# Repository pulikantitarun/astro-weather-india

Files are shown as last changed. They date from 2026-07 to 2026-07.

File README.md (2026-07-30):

# AstroWeather India — Non-Cellular V5.2

The current non-cellular edition of an affordable, Wi-Fi-connected and almost
entirely 3D-printable weather station for attended astrophotography.




> **Safety:** This is an attended-imaging aid, not a certified weather-safety
> controller. Never use the inexpensive rain plate as the sole input for an
> unattended observatory roof.

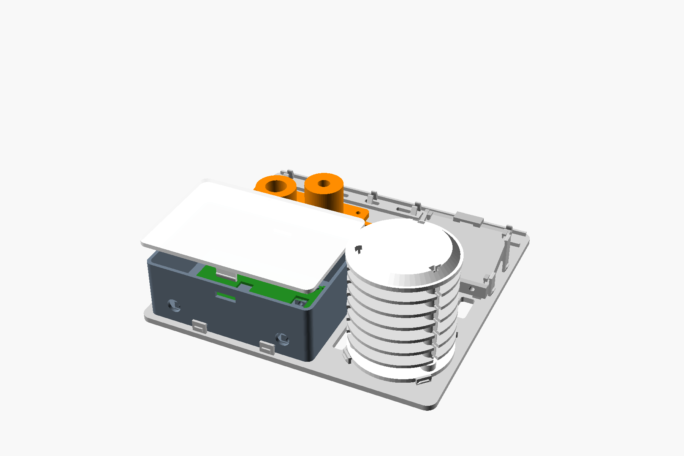
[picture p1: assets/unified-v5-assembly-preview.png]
Non-cellular V5.2 assembly


## Current printable version

The only current printable set is [`stl_unified_v5/`](stl_unified_v5/).

- `K5_Single_Unified_Base_Plate.stl` is one 210 × 200 mm backplane.
- All modules remain individually serviceable.
- The enclosure, lid, carrier, shield, sky head and rain cradle snap together.
- Six integrated jaws manage the rear cable loom.
- Physical surfaces are intentionally unmarked; filenames identify the parts.
- Print `L5_Fit_Kit_12_PIECES_PRINT_FIRST.stl` before the full build.

The original V5 export from commit `88b9ef8` must not be printed. V5.1 corrects
short carrier posts, dock interference, incomplete rain support, a mounting-slot
clash and open cable guides.

V5.2 also replaces H5, I5 and L5. In V5.1, H5's solid lower plate occupied the
same space as I5's PCB rails and snap fingers, so the sky-head halves could not
seat. V5.2 adds a raised protective rim, support pads, split snap pins and
matched 3.90 mm sockets.

Read the complete [V5.2 printing and assembly guide](docs/UNIFIED_V5.md).

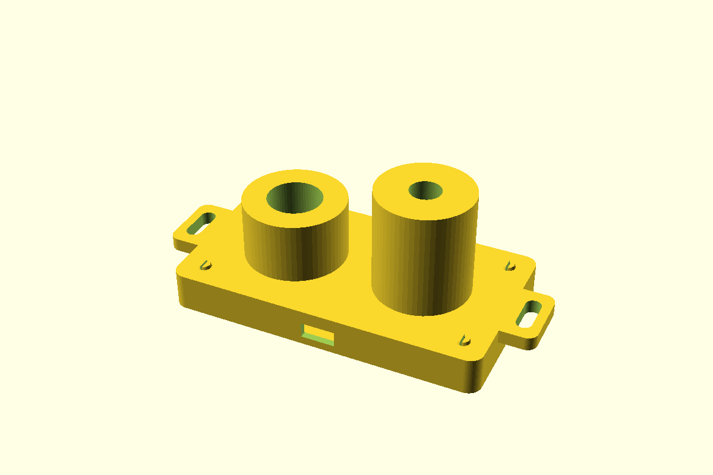
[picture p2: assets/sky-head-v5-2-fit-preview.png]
Corrected V5.2 sky-head fit


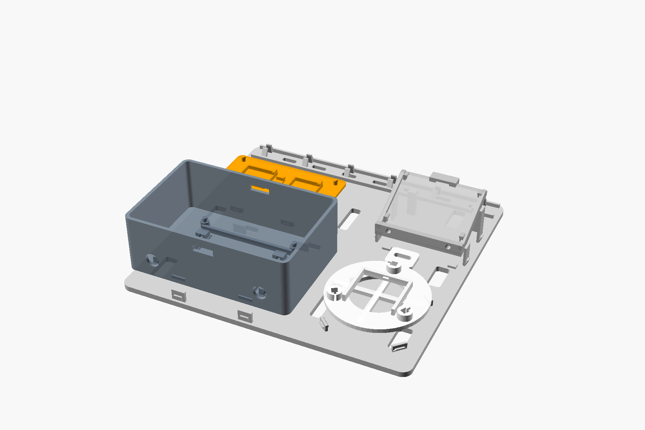
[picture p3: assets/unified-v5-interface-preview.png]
Non-cellular V5.2 interfaces


## Capabilities

- SHT31 temperature and humidity
- calculated dew point and dew margin
- MLX90614 zenith temperature and calibrated thermal-cloud estimate
- TSL2591 relative sky brightness
- reference-calibrated estimated SQM and heuristic Bortle class
- alternating-polarity rain sensing with a ten-minute unsafe latch
- configurable `OK` / `UNSAFE` imaging advisory
- responsive local web dashboard and authenticated settings page
- Wi-Fi setup-access-point fallback
- Telegram reports every 30 or 60 minutes plus rain/safety alerts
- JSON weather API
- ASCOM Alpaca ObservingConditions and SafetyMonitor
- native INDI Weather driver

The clarity score is a calibrated thermal-cloud score. It does not measure
seeing, turbulence, aerosols, transparency or stellar FWHM. SQM must be
calibrated against a reference meter; Bortle remains a heuristic estimate.

## Electronics

All digital sensors share the ESP32 I²C bus:

| ESP32 | Function |
|---|---|
| 3V3 | sensor power |
| GND | common ground |
| GPIO21 | SDA |
| GPIO22 | SCL |
| GPIO32 | rain electrode A network |
| GPIO33 | rain electrode B network |

Use the exposed-trace rain plate without its LM393 comparator board. See
[`docs/WIRING.csv`](docs/WIRING.csv), [`docs/BOM_India.csv`](docs/BOM_India.csv)
and [`docs/ASSEMBLY_GUIDE.md`](docs/ASSEMBLY_GUIDE.md).

## Firmware

```powershell
cd firmware
copy AstroWeather_ESP32\secrets.example.h AstroWeather_ESP32\secrets.h
python -m platformio run
python -m platformio run --target upload
```

If Wi-Fi is not configured, connect to `AstroWeather-Setup` and open
`http://192.168.4.1/settings`. Change the default administrator and setup
passwords immediately.

## Validation

All 15 current meshes pass watertightness, winding, component-count,
positive-volume, Z=0 and K1C/K2 build-envelope checks. Installed-state CGAL
intersections are empty for the carrier, enclosure dock, shield, sky head and
rain cradle. Firmware, configuration, SQM, ASCOM and INDI checks run in GitHub
Actions.

Digital checks do not prove PETG snap force, sensor-board clone dimensions,
weather sealing or field calibration. Approve the supplied fit kit and perform
staged attended testing.

## Source and licence

The editable entry point is
[`cad/AstroWeather_Unified_Base_v5.scad`](cad/AstroWeather_Unified_Base_v5.scad).
The other SCAD files in `cad/` are required source modules for that current
design, not separately supported printable editions.

Licensed under GNU AGPL-3.0-or-later.

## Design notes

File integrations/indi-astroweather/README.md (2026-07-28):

# AstroWeather INDI driver

This driver reads the station's local `/api/weather` JSON endpoint and exposes
standard INDI Weather parameters plus rain and estimated Bortle details.

## Build and install

On a Debian/Ubuntu-based INDI computer:

```bash
sudo apt update
sudo apt install build-essential cmake libindi-dev libcurl4-openssl-dev nlohmann-json3-dev
cmake -S . -B build -DCMAKE_BUILD_TYPE=Release
cmake --build build --parallel
sudo cmake --install build
```

Restart the INDI server, select **AstroWeather India** under Weather, then set
the endpoint to `http://astroweather.local/api/weather`.

The driver is intended for normal INDI installations including KStars/Ekos,
Astroberry and StellarMate. Closed appliances that do not permit third-party
INDI driver installation, including standard ASIAIR firmware, are not
guaranteed to support it.

`WEATHER_SKY_QUALITY` is only updated after `SQM_CAL_OFFSET` is calibrated in
the ESP32 firmware. The binary rain plate is exposed as a dry/wet safety
parameter; it is not misreported as a measured rain rate.

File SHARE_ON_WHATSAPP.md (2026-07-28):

# WhatsApp sharing text

## Short group message

🌦️ **AstroWeather India — DIY weather station for astrophotography**

I have designed and open-sourced an affordable ESP32 weather station for
attended astrophotography. It measures temperature, humidity, dew point,
dew margin, infrared cloud cover, relative sky brightness and rain, and provides
a live Wi-Fi dashboard with an imaging OK/UNSAFE advisory.

✅ Almost completely 3D printable
✅ Support-free parts for Creality K1C and K2 printers
✅ ESP32 web dashboard + JSON API
✅ Locally calibrated cloud and rain thresholds
✅ All STL, OpenSCAD, firmware, wiring and assembly files included
✅ AGPL-3.0 open-source licence

💰 Approximate complete cost: **₹2,900 plus shipping**
Electronics and assembly supplies: ₹2,617.70
PETG and mounting straps: approximately ₹250

GitHub: https://github.com/pulikantitarun/astro-weather-india

Version 1.2 also works as an ASCOM Alpaca ObservingConditions + SafetyMonitor
device directly from the ESP32, and includes a native INDI Weather driver for
KStars/Ekos-compatible systems.

Version 1.3 adds a phone-friendly Settings page for Wi-Fi, Telegram and weather
limits, with optional 30/60-minute reports plus immediate rain and unsafe
alerts. No additional electronics are needed.

⚠️ This is an attended-imaging advisory device, not a certified unattended-roof
safety controller.

## Detailed group message

🔭🌦️ **AstroWeather India — affordable open-source astrophotography weather
station**

I wanted a practical weather monitor that Indian astrophotographers could build
without expensive imported observatory hardware, so I designed this modular
ESP32 station.

It provides:

• air temperature and humidity
• calculated dew point and dew margin
• infrared zenith temperature
• locally calibrated cloud percentage
• thermal clarity score
• relative zenith lux, full-spectrum and IR counts
• reference-calibrated estimated SQM and estimated Bortle class
• corrosion-reduced rain detection with a 10-minute unsafe latch
• live phone/PC dashboard over Wi-Fi
• JSON API for future Home Assistant, Node-RED or observatory integration
• automatic imaging OK/UNSAFE advisory

The printable package has physically labelled A-L parts, a radiation shield,
twin-sensor sky head, sloped rain mount, electronics box, fit-test pieces and
support-free K1C/K2 print orientations.

**Approximate July 2026 India cost**

• ESP32, MLX90614, rain sensor, wiring, solder, flux and power: ₹1,550
• SHT31: ₹312.70
• TSL2591: ₹755
• PETG and straps: about ₹250
• Complete estimate: **₹2,867.70 before shipping**

All STL files, editable OpenSCAD, ESP32 firmware, BOM, wiring, calibration
guide, validation report and assembly visuals are available here:

https://github.com/pulikantitarun/astro-weather-india

Version 1.2 adds direct ASCOM Alpaca discovery, ObservingConditions and
SafetyMonitor support, plus a buildable native INDI Weather driver for
KStars/Ekos, Astroberry and StellarMate-style installations.

Version 1.3 adds persistent web configuration and optional Telegram weather
reports, rain alerts and safe/unsafe state-change notifications.

Licensed under **AGPL-3.0-or-later** so improvements remain open.

Important: this is intended for supervised imaging. It is not a certified
weather instrument and should not be the sole safety sensor for an unattended
observatory roof.

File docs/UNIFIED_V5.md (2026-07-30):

# V5.2 unified tool-less base

V5 keeps the clean, unmarked V4 snap parts and replaces the separate mounting
arrangement with one `K5_Single_Unified_Base_Plate.stl`.

V5 assembled on one base

V5 snap docks

## What the single plate holds

- A5 electronics enclosure on four push-out service tabs;
- C5 radiation shield in a four-finger circular nest;
- I5/H5 sky head in a four-clip rectangular nest;
- J5 rain cradle at its working slope on four integrated support pads;
- the complete loom in a rear channel with six snap-over bridges.

All sensor assemblies remain individually removable. K5 is the only mounting
backplane.

## V5.1 engineering corrections

The original V5 export in commit `88b9ef8` must not be printed. Its four
carrier pegs were part of the A5 mesh and were not floating, but their retaining
heads ended below the top of O5, so the carrier could sit on them without
latching. A broader installed-state audit also found positive-volume dock
interference, incomplete rain-cradle support, a mounting slot cutting a rain
pedestal and open cable guides that could not retain the loom.

V5.1 corrects those issues as follows:

- all four O5 carrier posts now support the carrier at Z=8.0 mm and project
  their retaining heads 1.0 mm above its 2 mm base;
- the four A5 dock arms no longer intersect the enclosure catch ledges;
- shield and rain-clip root gussets grow away from the captured parts;
- the rain cradle seats on connected front pads and two 6 mm-wide rear
  pedestals whose top plane matches the actual J5 convex-hull underside;
- the rear-right mounting slot was moved clear of its rain pedestal;
- the rear loom lane now uses flexible jaws with a 4.6 mm insertion throat.

Final CGAL installed-state intersections are empty for the carrier, A5 dock,
shield dock, sky dock and rain dock. Surface seating is tested separately from
positive-volume collision.

## V5.2 sky-head correction

V5.1 H5 and I5 cannot close correctly: the four-millimetre H5 plate intersects
I5's raised PCB rails and snap fingers. The intended seated position produced
approximately 1,045 mm³ of collision in the CGAL audit.

V5.2 replaces H5, I5 and L5:

- I5 has a 7 mm seating rim that raises H5 above every PCB feature;
- four 7 mm support pads prevent rocking;
- four longer split pins compress during insertion and recover above H5;
- H5 sockets are 3.90 mm with 0.15 mm nominal diametral snap interference;
- a front rim notch routes the sensor loom without pinching it;
- the installed-state CGAL intersection is empty.

Do not combine a V5.1 H5 or I5 with the corrected counterpart. Reprint all
three replacement files so the socket, pin and fit coupon remain matched.

Corrected V5.2 sky-head fit

## Critical mounting orientation

K5 must remain approximately horizontal and level. The sky apertures must point
at the zenith and the rain plate must retain its designed upward slope.

Do not fasten K5 flat against a vertical wall or mast. Use a horizontal shelf,
mast-top tray or 90-degree metal/printed support bracket beneath it. The long
slots are for securing K5 to that horizontal support.

## Print L5 first

`L5_Fit_Kit_12_PIECES_PRINT_FIRST.stl` contains the ten V4 interface tests plus
an exact K5 edge clip and a 3 mm captured-edge coupon.

Use PETG, a 0.4 mm nozzle, 0.20 mm layers, four walls, five bottom layers,
20% gyroid and supports off. Every joint must click with finger pressure,
release without pliers, and survive ten cycles without whitening.

## Printing K5

K5 is 210 x 200 x 31.2 mm. It fits a 220 x 220 x 250 mm K1C bed with 5 mm
clearance on each X side and 10 mm on each Y side.

- Confirm the build plate is actually 220 x 220 mm and correctly centered.
- Use the supplied flat orientation.
- Do not use a wide external brim; it can exceed the K1C printable area.
- Use five walls, six bottom layers and 25% gyroid for the full backplane.
- PETG is preferred; ASA is better outdoors if the printer is configured for it.
- Clean the bed and verify first-layer calibration across the full area.
- The rain pedestals, cable jaws and small snap hooks print support-free.

## Assembly order

1. Approve all twelve L5 coupons.
2. Press O5 and the electronics into A5, then complete and bench-test wiring.
3. Press A5 into the front-left dock until all four base fingers click.
4. Assemble C5, three F5 rods, six D5 louvers, G5 and E5; press the completed
   shield into the circular dock one clip at a time.
5. Install the sky PCBs in I5, route their loom, click H5 onto I5, then press
   the completed sky head into the rear-left rectangular dock.
6. Rotate J5 from its print orientation into its working slope. Rest it on the
   four rear-right support pads and press each side lip beneath the tall clips.
7. Route all low-voltage wiring into the rear loom lane. Press it below each of
   the six bridges and leave drip/service loops before each sensor.
8. Fit N5 grommets and close B5 only after all live sensor tests pass.

## Removing a module

- A5: push its four K5 fingers outward while lifting the enclosure evenly.
- Shield: support C5 beside a clip and release opposite clips in pairs.
- Sky head: flex only the four low tray clips; never pull on the sensor towers.
- Rain cradle: support the sloped tray and release the low pair before the tall
  rear pair.
- Loom: peel one cable section sideways from each bridge; do not pull on a PCB.

## Print quantities

| STL | Quantity |
|---|---:|
| A5, B5, C5, E5, G5, H5, I5, J5, K5, O5 | 1 each |
| D5 louver | 6 |
| F5 rod | 3 |
| M5 cable clip | 6, only where the loom leaves K5 |
| N5 split grommet | 2 |
| L5 calibration kit | 1 first |

## Physical and outdoor limits

Mesh validation cannot prove snap force, clone-PCB compatibility, wind loading,
fatigue, UV life or weather sealing. K5 creates a larger wind-catching assembly
than the separate mounts. Use redundant UV-resistant safety ties after physical
testing if the station is exposed above people or equipment.

Snap fits do not waterproof A5. Keep cable entries downward, use drip loops and
suitable sealing, and place the electronics beneath shelter where possible.
This remains an advisory station, not the sole unattended roof-safety input.

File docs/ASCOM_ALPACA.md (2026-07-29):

# ASCOM Alpaca setup

The current AstroWeather firmware exposes ASCOM Alpaca directly from the ESP32. No Windows
driver executable, bridge computer or additional electronics are required.

## Devices

The station advertises two independent device number `0` entries:

- **AstroWeather Observing Conditions** — air temperature, humidity, dew point,
  cloud cover, sky temperature, sky brightness and calibrated estimated SQM.
- **AstroWeather Safety Monitor** — the station's combined advisory result,
  including the dry/wet rain plate state.

Both use HTTP port 80. Standard UDP Alpaca discovery listens on port 32227.
The unique IDs are derived from the ESP32 MAC address and remain stable for
that board.

## Windows setup

1. Put the ESP32 and Windows imaging computer on the same local network.
2. Flash the current firmware and confirm
   `http://astroweather.local/api/weather` opens.
3. In an Alpaca-aware ASCOM chooser, discover devices and select the
   AstroWeather Observing Conditions and/or Safety Monitor device.
4. If discovery is blocked, add the device manually using
   `astroweather.local`, port `80`, device number `0`.
5. Permit private-network UDP port `32227` and TCP port `80` in the Windows
   firewall if required.

The endpoints can be checked in a browser:

```text
http://astroweather.local/management/apiversions
http://astroweather.local/management/v1/configureddevices
http://astroweather.local/api/v1/observingconditions/0/temperature
http://astroweather.local/api/v1/safetymonitor/0/issafe
```

## Data mapping

| ASCOM property | Station field | Behaviour |
|---|---|---|
| `Temperature` | `air_c` | degrees Celsius |
| `Humidity` | `humidity` | 0–100% |
| `DewPoint` | `dew_c` | degrees Celsius |
| `CloudCover` | `cloud_percent` | 0–100% |
| `SkyTemperature` | `sky_c` | MLX90614 zenith IR temperature |
| `SkyBrightness` | `lux` | TSL2591 lux |
| `SkyQuality` | `sqm_estimate` | only after reference calibration |
| `IsSafe` | `advisory_safe` | combined advisory, including rain |

Pressure, wind, seeing/FWHM and measured rain rate are deliberately reported
as unsupported. The rain plate detects wet/dry state but cannot measure
millimetres per hour.

## Safety and SQM limits

`IsSafe` is an advisory, not a certified roof-control interlock. Use a
fail-safe, independent rain/roof system for unattended operation.

`SkyQuality` returns an ASCOM value-not-set error until `SQM_CAL_OFFSET` is
calibrated. This prevents an uncalibrated light count from appearing as a
real SQM measurement.

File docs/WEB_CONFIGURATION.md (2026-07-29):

# Web configuration portal

The current firmware stores operating settings in the ESP32's non-volatile memory.
Wi-Fi, Telegram and weather limits can therefore be changed from a phone or
computer without editing source code or reflashing.

## First setup

1. Flash the firmware.
2. If it cannot join a configured Wi-Fi network, connect your phone or computer
   to:
   - network: `AstroWeather-Setup`
   - default password: `astroclear`
3. Open `http://192.168.4.1/settings`.
4. Sign in with:
   - username: `admin`
   - default password: `astroadmin`
5. Immediately set a new settings password and setup-access-point password.
6. Enter the normal Wi-Fi SSID and password.
7. Configure the required weather and Telegram options.
8. Select **Save and restart**.

After a successful connection, use:

```text
http://astroweather.local/
http://astroweather.local/settings
```

If the hostname was changed, replace `astroweather` with the new hostname.

## Configurable values

### Network

- local hostname;
- Wi-Fi SSID and password;
- fallback setup-access-point password;
- settings-page password.

### Telegram

- enable/disable;
- bot token and chat/group ID;
- reports off, every 30 minutes or every hour;
- startup, unsafe, recovery and rain alerts;
- local UTC offset, defaulting to India Standard Time (`330` minutes).

### Weather and calibration

- humidity unsafe limit;
- minimum dew margin;
- cloud unsafe percentage;
- rain raw threshold;
- rain unsafe latch from 1 to 120 minutes;
- clear and overcast thermal calibration deltas;
- SQM calibration offset.

Passwords and the Telegram token are write-only: the page never displays their
stored values. A blank secret field keeps the current value. The Telegram form
also has an explicit option to delete the saved token.

## Persistence and security

Settings survive normal restarts and firmware updates because they are stored
in ESP32 NVS. Erasing the ESP32 flash also erases them.

The configuration page uses HTTP Basic authentication, but local HTTP is not
encrypted. Keep AstroWeather on a trusted private network, change both default
passwords and never expose port 80 through router port forwarding. Wi-Fi
passwords and Telegram tokens must be available to the firmware and are not
encrypted in ordinary ESP32 NVS; physical access to the device should therefore
be treated as access to those credentials.

The public dashboard, JSON API, ASCOM Alpaca and INDI service remain available
without settings credentials so astronomy clients continue to work.

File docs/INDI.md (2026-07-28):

# INDI / KStars / Ekos setup

The source for the native driver is in
`integrations/indi-astroweather`. It polls the ESP32 JSON endpoint and exposes
INDI Weather values to KStars/Ekos and other standard INDI clients.

## Install

Run these commands on the Linux computer that hosts INDI:

```bash
sudo apt update
sudo apt install build-essential cmake libindi-dev libcurl4-openssl-dev nlohmann-json3-dev
cd integrations/indi-astroweather
cmake -S . -B build -DCMAKE_BUILD_TYPE=Release
cmake --build build --parallel
sudo cmake --install build
```

Restart the INDI service. Add **AstroWeather India** as a Weather device, open
its Options tab and set:

```text
http://astroweather.local/api/weather
```

If mDNS is not available, reserve an IP address for the ESP32 in the router
and use `http://192.168.x.x/api/weather`.

## Values

The driver supplies:

- temperature, humidity and dew point;
- cloud cover and sky temperature;
- calibrated estimated sky quality in mag/arcsec²;
- estimated Bortle class;
- dry/wet rain state;
- `WEATHER_FORECAST = 0` for advisory safe or `3` for unsafe.

The rain state and forecast are critical safety parameters. SQM/Bortle are
only updated when calibrated finite values are present in the ESP32 response.

This works with INDI installations that permit third-party driver binaries,
including typical KStars/Ekos, Astroberry and StellarMate systems. Standard
ASIAIR firmware does not provide a supported route for installing arbitrary
third-party INDI drivers, so ASIAIR compatibility is not claimed.

As with the dashboard and Alpaca interface, the INDI status is advisory only
and must not be the sole unattended roof-closing input.

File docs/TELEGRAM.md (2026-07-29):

# Telegram weather reports

The current AstroWeather firmware can send outbound Telegram reports directly from the ESP32.
No additional computer, cloud subscription or electronic component is needed.

## Create the bot

1. Open the official `@BotFather` account in Telegram.
2. Send `/newbot` and follow its instructions.
3. Copy the generated bot token.
4. Open the new bot and send `/start`. A bot cannot initiate a private
   conversation until the user has contacted it.
5. For a group, add the bot to the group and send a message that it can receive.
6. Obtain the private chat or group `chat_id` from the bot's updates.

Treat the token like a password: anyone with it can control the bot. If it is
ever exposed, revoke it through BotFather.

## Configure AstroWeather

1. Open `http://astroweather.local/settings`.
2. Enable Telegram.
3. Paste the bot token and destination chat/group ID.
4. Choose reports every 30 minutes, every hour, or off.
5. Enable the desired event messages:
   - station online;
   - weather changed to unsafe;
   - conditions recovered to safe;
   - rain detected.
6. Keep the UTC offset at `330` for India Standard Time.
7. Save, allow the station to restart, reopen Settings and select
   **Send Telegram test**.

Example:

```text
REGULAR WEATHER REPORT
AstroWeather India - 2026-07-28 21:30

Temperature: 23.4 C
Humidity: 78.0 %
Dew point: 19.4 C
Dew margin: 4.0 C
Cloud cover: 16 %
Clarity: 84 / 100
SQM estimate: 20.65
Estimated Bortle: 4
Rain: dry
Status: ADVISORY SAFE
```

SQM and Bortle are labelled unavailable until a valid SQM calibration exists.
Rain triggers immediately and the safe recovery message is delayed until the
configured rain latch and all other unsafe conditions have cleared.

## Reliability and privacy

- Telegram uses certificate-validated HTTPS and NTP-corrected time.
- The token is never returned by the dashboard or JSON API.
- No inbound router port or Telegram command polling is required.
- If internet access fails, the dashboard, API, ASCOM and INDI remain local and
  operational.
- Event messages that occur entirely during an outage cannot be recovered
  because this inexpensive design does not include persistent message queuing.
- Telegram is an advisory notification channel, not a roof safety interlock.

Official references:

- [Telegram Bot API](https://core.telegram.org/bots/api)
- [Telegram BotFather and bot features](https://core.telegram.org/bots/features)

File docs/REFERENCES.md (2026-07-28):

# Technical references

- [Adafruit TSL2591 gain, integration time, raw channels and lux calculation](https://learn.adafruit.com/adafruit-tsl2591/wiring-and-test)
- [Unihedron SQM-LR operator manual and mag/arcsec² response format](https://unihedron.com/projects/darksky/cd/SQM-LR/SQM-LR_Users_manual.pdf)
- [Introducing the Bortle Dark-Sky Scale, John E. Bortle](https://www.skyandtelescope.org/wp-content/uploads/BortleDarkSkyScale.pdf)
- [ASCOM Master ObservingConditions interface](https://ascom-standards.org/newdocs/observingconditions.html)
- [ASCOM Alpaca API reference](https://ascom-standards.org/AlpacaDeveloper/ASCOMAlpacaAPIReference.html)
- [INDI WeatherInterface documentation](https://docs.indilib.org/interfaces/weather-interface.html)
- [Telegram Bot API](https://core.telegram.org/bots/api)
- [Telegram BotFather and bot features](https://core.telegram.org/bots/features)

The TSL2591 does not natively report SQM. AstroWeather applies the astronomical
magnitude relationship to fixed-gain visible counts after calibration against a
reference SQM. The reported Bortle value is a heuristic label and is not a
replacement for the visual assessment described by Bortle.

The network integrations intentionally use the published ASCOM Alpaca and INDI
Weather interfaces. Unsupported physical measurements such as pressure, wind,
seeing and rain rate are not inferred.

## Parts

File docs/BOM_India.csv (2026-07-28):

Item | Qty | Approximate INR | Required
ESP32 38-pin DevKit | 1 | 381 | Yes
SHT31 temperature/humidity breakout | 1 | 312.70 | Yes
MLX90614 GY-906 IR thermometer module | 1 | 670 | Yes
TSL2591 19x16 mm light sensor | 1 | 755 | Yes
Exposed-trace rain sensor module | 1 | 49 | Yes
Mixed M-M M-F F-F jumper set | 1 | 139 | Yes
100k resistor pack | 1 | 13 | Yes
1M resistor pack | 1 | 13 | Yes
2x3 inch vero board | 1 | 13 | Yes
4 mm heat-shrink tube 1 m | 1 | 13 | Yes
Electronics flux 10 g | 1 | 25 | Yes
Solder wire 10 g | 1 | 39 | Yes
5 V 2 A adapter with Micro-USB cable | 1 | 195 | Yes
PETG filament approximately 250 g | 1 | 200 | Yes
Reusable mounting straps | 2 | 50 | Yes
Conformal coating for boards only | 1 | 250 | Optional
ELECTRONICS AND ASSEMBLY SUPPLIES SUBTOTAL |  | 2617.70 | Before shipping
ESTIMATED COMPLETE BUILD |  | 2867.70 | Before shipping excluding optional coating

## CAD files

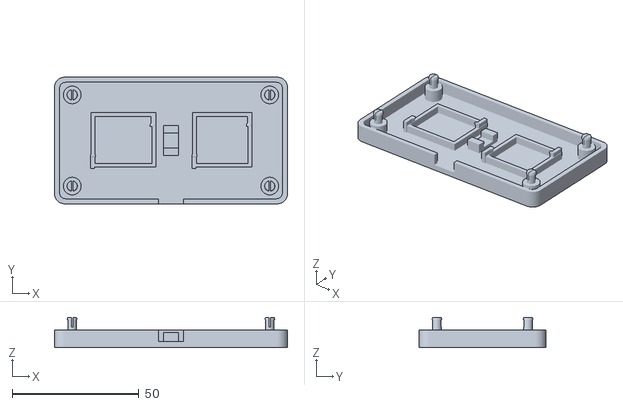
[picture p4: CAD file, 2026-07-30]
stl_unified_v5/I5_PCB_Snap_Sky_Tray.stl
92.0 x 50.0 x 11.9

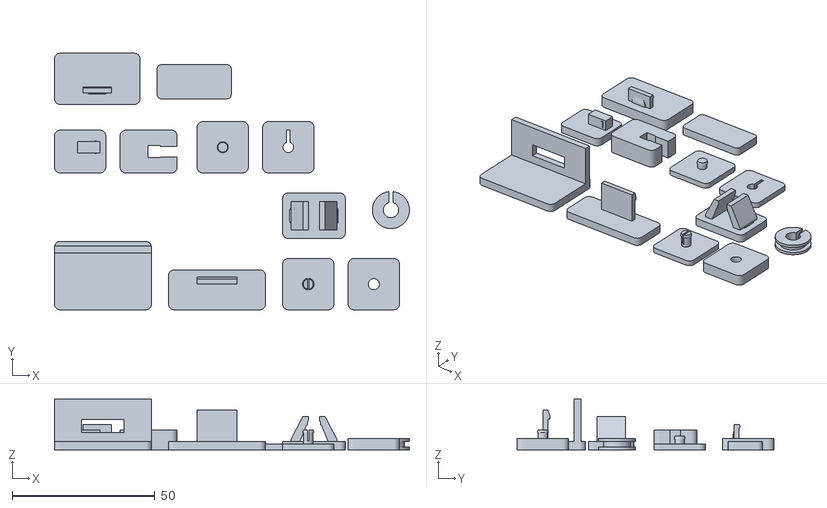
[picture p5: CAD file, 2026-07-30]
stl_unified_v5/L5_Fit_Kit_12_PIECES_PRINT_FIRST.stl
124.5 x 90.0 x 17.8

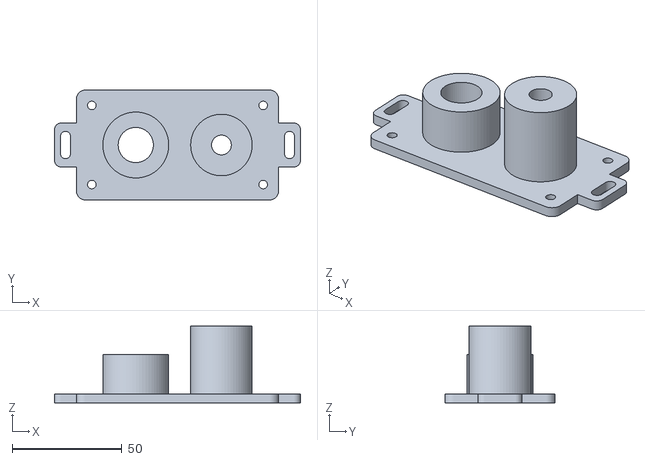
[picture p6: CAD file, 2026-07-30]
stl_unified_v5/H5_Sky_Head_Top.stl
112.0 x 50.0 x 35.0

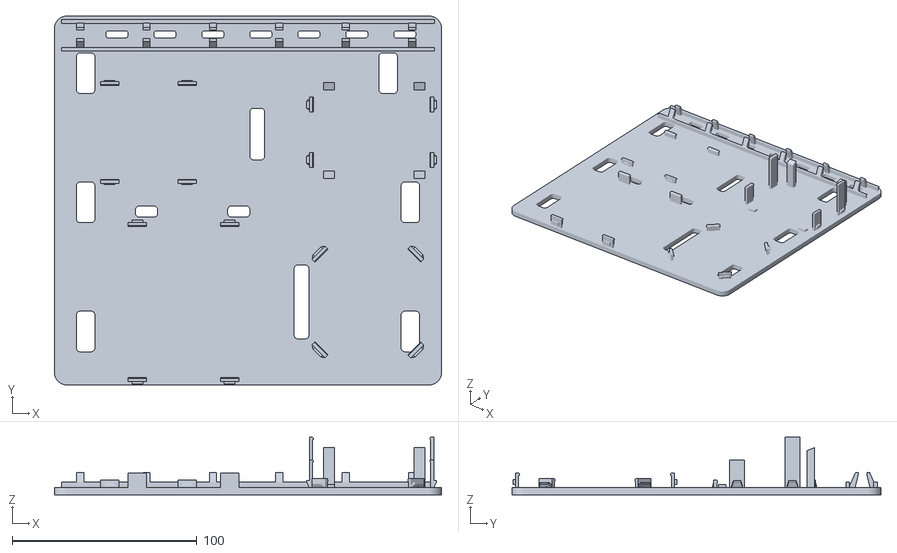
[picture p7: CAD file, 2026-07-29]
stl_unified_v5/K5_Single_Unified_Base_Plate.stl
210.0 x 200.0 x 31.2

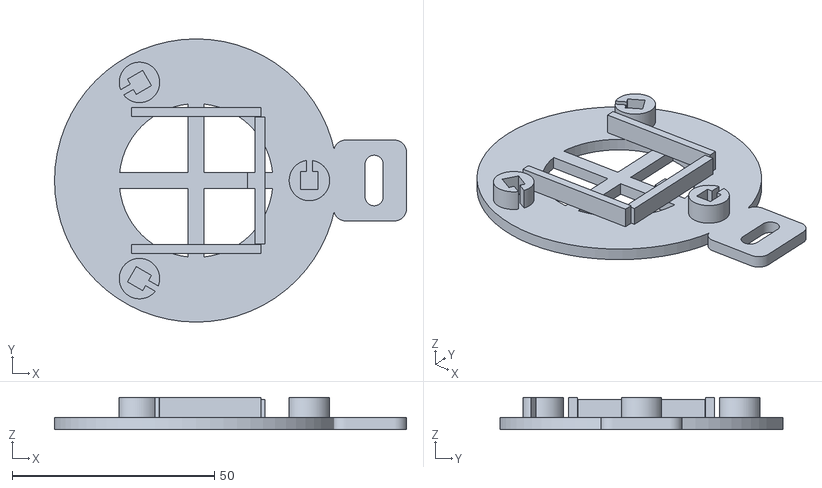
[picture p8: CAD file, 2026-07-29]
stl_unified_v5/C5_Click_Shield_Base.stl
87.0 x 70.0 x 8.00

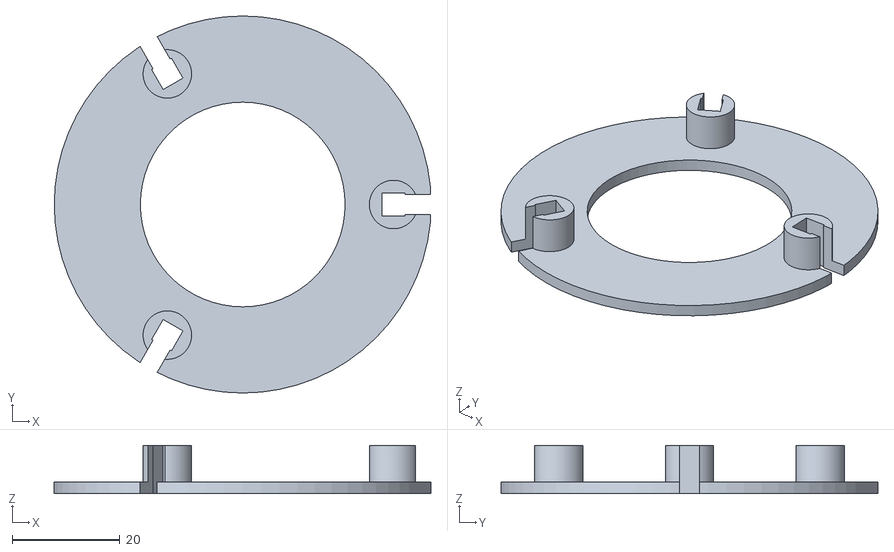
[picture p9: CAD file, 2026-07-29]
stl_unified_v5/D5_Side_Snap_Louver_PRINT_6.stl
69.9 x 70.0 x 9.00

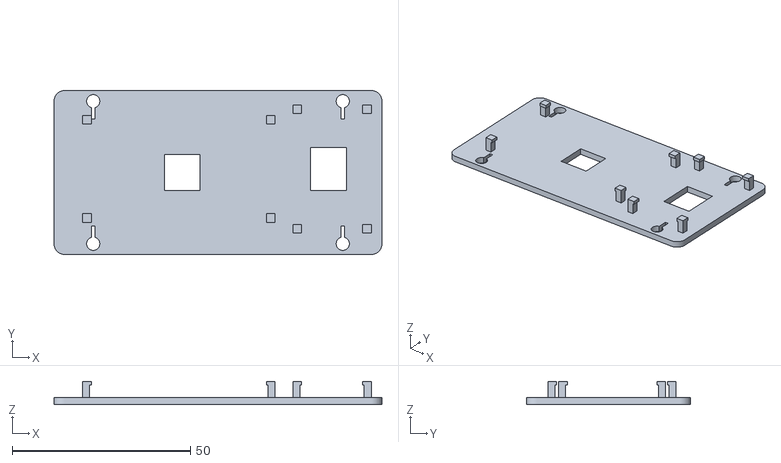
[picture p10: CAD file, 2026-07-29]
stl_unified_v5/O5_Snap_Electronics_Carrier.stl
92.0 x 46.0 x 6.50

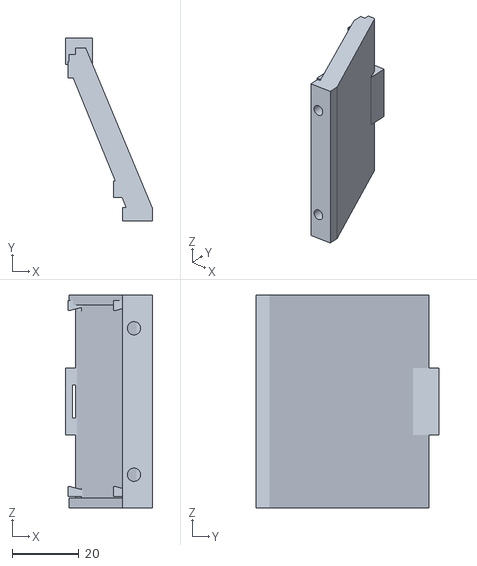
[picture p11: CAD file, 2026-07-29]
stl_unified_v5/J5_Compliant_Rain_Cradle.stl
26.0 x 55.0 x 64.0

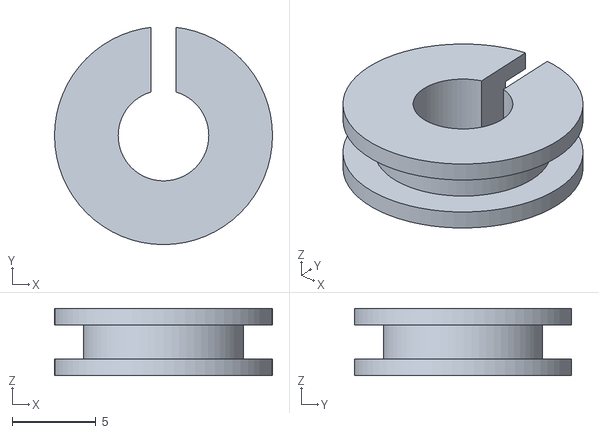
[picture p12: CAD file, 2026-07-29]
stl_unified_v5/N5_Split_Grommet_PRINT_2.stl
13.0 x 13.0 x 4.00

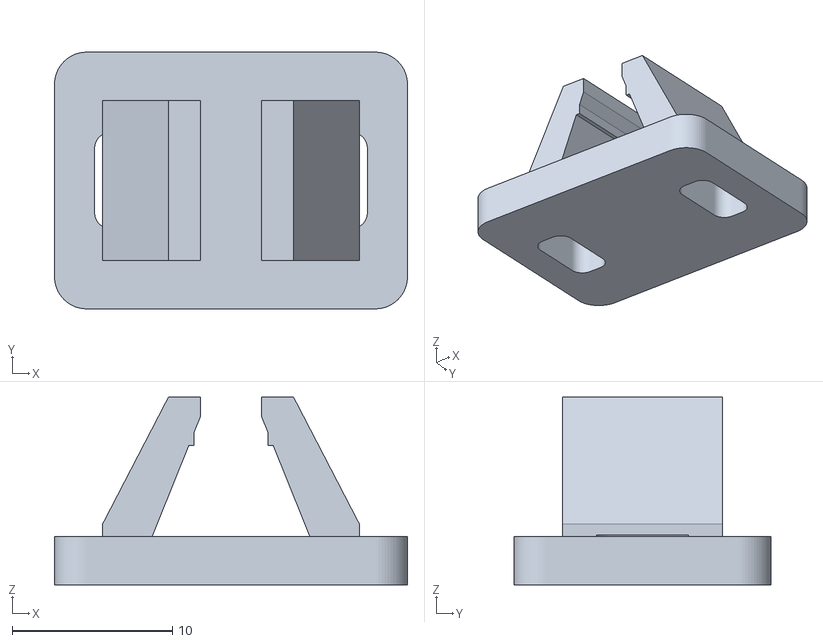
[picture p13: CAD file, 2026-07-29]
stl_unified_v5/M5_Cable_Clip_PRINT_6.stl
22.0 x 16.0 x 11.7

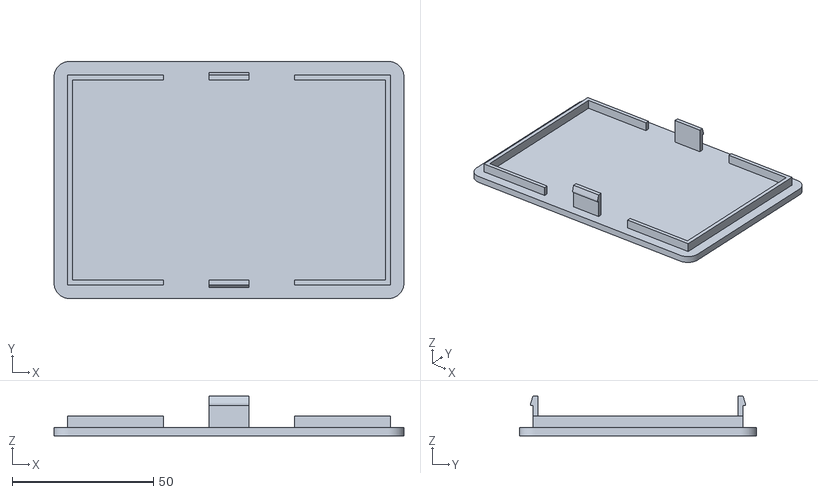
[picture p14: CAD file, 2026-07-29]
stl_unified_v5/B5_Release_Lid.stl
124.0 x 84.0 x 14.0

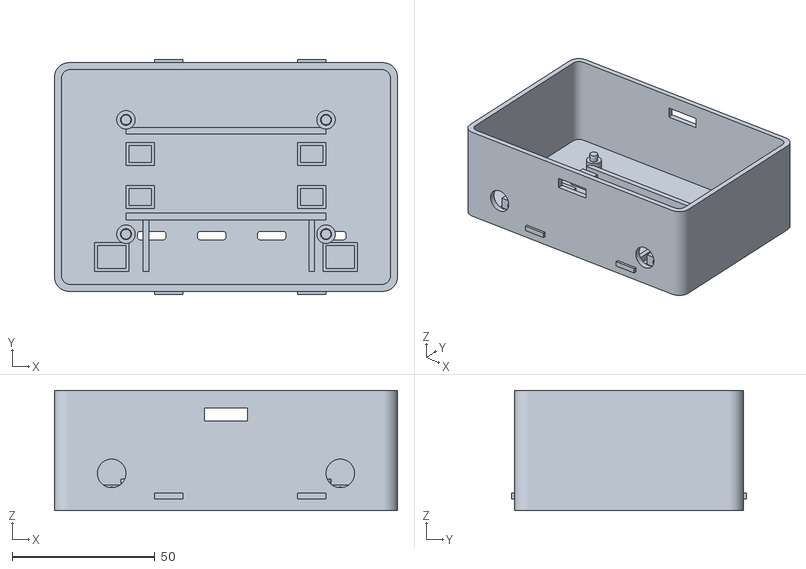
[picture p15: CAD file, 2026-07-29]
stl_unified_v5/A5_Clean_Electronics_Box.stl
120.0 x 82.2 x 42.0

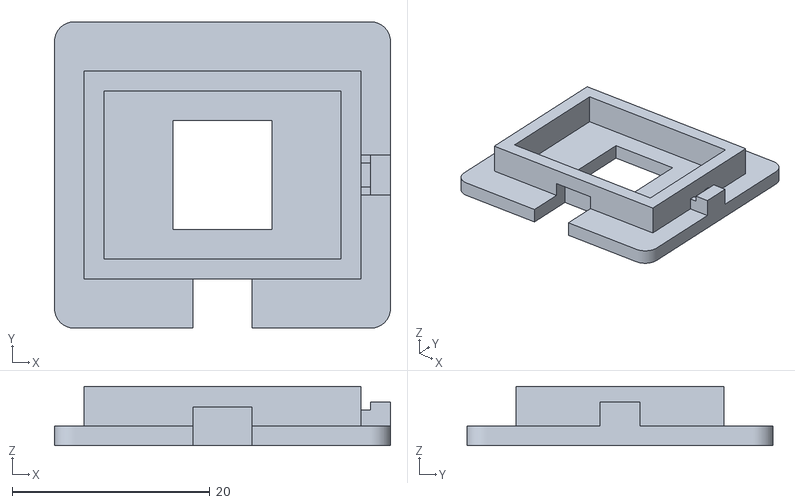
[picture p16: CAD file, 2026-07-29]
stl_unified_v5/G5_Click_SHT31_Sled.stl
34.0 x 31.0 x 6.00

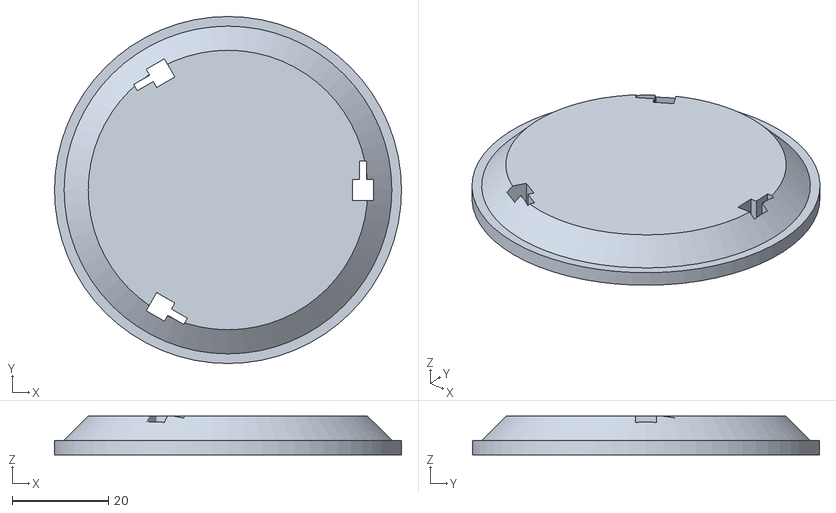
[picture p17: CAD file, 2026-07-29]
stl_unified_v5/E5_Click_Shield_Roof.stl
72.0 x 72.0 x 8.00

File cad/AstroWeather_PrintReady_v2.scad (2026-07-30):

/*
  SPDX-License-Identifier: AGPL-3.0-or-later
  Copyright (C) 2026 Tarun and contributors

 AstroWeather India - K1C/K2 print-ready mechanical revision 2

 Every exported STL is placed in its intended print orientation.
 No supports are intended with a 0.4 mm nozzle and 0.20 mm layers.

  1 A_Electronics_Box
  2 B_Box_Lid
  3 C_Shield_Base
  4 D_Shield_Louver (print 6)
  5 E_Shield_Roof
  6 F_Shield_Rod (print 3)
  7 G_SHT31_Sled
  8 H_Sky_Head_Top
  9 I_Sky_Head_Tray
 10 J_Rain_Plate_Mount
 11 K_Mounting_Plate
 12 L_Fit_Kit_4_PIECES (print first)
 90 exploded assembly preview
*/

$fn = 64;
part_id = 90;
fit = 0.35;
wall = 2.4;
lid_clearance_per_side = 0.30;
peg_d = 3.60;
// H5 socket is deliberately larger than the legacy friction socket. The
// current split snap pin provides retention without relying on an undersized
// printed hole.
peg_clearance_d = 0.30;
board_clearance = 0.50;

module rr2d(s=[20,20],r=3) {
    hull()
        for (x=[r,s[0]-r], y=[r,s[1]-r])
            translate([x,y]) circle(r=r);
}

module rrbox(s=[20,20,5],r=3) {
    linear_extrude(s[2]) rr2d([s[0],s[1]],r);
}

module mark(txt, p=[0,0,0], size=5, h=0.55) {
    if (is_undef($show_part_labels) || $show_part_labels)
        translate(p) linear_extrude(h)
            text(txt,size=size,font="Liberation Sans:style=Bold",
                 halign="center",valign="center");
}

module A_box() {
    difference() {
        rrbox([120,80,42],5);
        translate([wall,wall,3])
            rrbox([120-2*wall,80-2*wall,42],3.2);
        // Down-facing cable entries when installed vertically.
        translate([20,-1,13]) rotate([-90,0,0]) cylinder(d=8,h=wall+2);
        translate([100,-1,13]) rotate([-90,0,0]) cylinder(d=8,h=wall+2);
        for (x=[25:22:91])
            translate([x,15,-0.1]) cube([12,3,4]);
    }
    // Generic ESP32/perfboard rails.
    for (y=[22,56]) translate([25,y,3]) cube([70,2.2,4]);
    // Cable anchors.
    for (x=[16,104])
        translate([x,12,3]) difference() {
            cube([8,8,6],center=true);
            rotate([90,0,0]) cylinder(d=3.5,h=10,center=true);
        }
    mark("A  BOX",[60,40,3],6);
}

module B_lid() {
    union() {
        rrbox([124,84,3],5.5);
        // Friction plug. Sand lightly if the fit coupon is tight.
        translate([(124-(115.2-2*lid_clearance_per_side))/2,
                   (84-(75.2-2*lid_clearance_per_side))/2,3])
            difference() {
                rrbox([115.2-2*lid_clearance_per_side,
                       75.2-2*lid_clearance_per_side,4],3);
                translate([2.4,2.4,-0.1])
                    rrbox([110.4-2*lid_clearance_per_side,
                           70.4-2*lid_clearance_per_side,4.2],2);
            }
        mark("B  LID",[62,42,3],6);
    }
}

module C_shield_base() {
    difference() {
      union() {
        difference() {
            cylinder(d=70,h=3);
            translate([0,0,-0.1]) cylinder(d=38,h=3.2);
        }
        // Crossbars and sled guides.
        translate([-31,-2,0]) cube([62,4,3]);
        translate([-2,-31,0]) cube([4,62,3]);
        translate([-16,-18,3]) cube([32,2.2,5]);
        translate([-16,15.8,3]) cube([32,2.2,5]);
        // Square rod sockets.
        for (a=[0,120,240])
            rotate([0,0,a]) translate([28,0,0])
                difference() {
                    cylinder(d=10,h=8);
                    translate([-2.25,-2.25,2]) cube([4.5,4.5,6.2]);
                }
        translate([34,-10,0]) rrbox([18,20,3],3);
        mark("C",[0,-27,3],5);
      }
      translate([44,0,-0.1]) hull() {
          translate([0,-4,0]) cylinder(d=4.5,h=3.2);
          translate([0,4,0]) cylinder(d=4.5,h=3.2);
      }
    }
}

module D_louver() {
    difference() {
        union() {
            difference() {
                cylinder(d=70,h=2.2);
                translate([0,0,-0.1]) cylinder(d=38,h=2.4);
            }
            // Integrated spacers face upward; each new louver rests on them.
            for (a=[0,120,240])
                rotate([0,0,a]) translate([28,0,0])
                    cylinder(d=9,h=9);
            mark("D",[0,-27,2.2],4);
        }
        for (a=[0,120,240])
            rotate([0,0,a]) translate([28,0,-0.1])
                translate([-2.35,-2.35,0]) cube([4.7,4.7,9.2]);
    }
}

module E_roof() {
    difference() {
        union() {
            cylinder(d=72,h=3);
            translate([0,0,3]) cylinder(d1=68,d2=58,h=5);
            mark("E",[0,-25,8],4);
        }
        for (a=[0,120,240])
            rotate([0,0,a]) translate([28,0,-0.1])
                translate([-2.3,-2.3,0]) cube([4.6,4.6,8.3]);
    }
}

module F_rod() {
    // Printed flat. Three identical rods slide through the D louvers.
    union() {
        translate([2,0,0]) cube([64,4,4]);
        translate([0,0,0]) hull() {
            translate([0.8,0.4,0.4]) cube([1.2,3.2,3.2]);
            translate([2,0,0]) cube([1,4,4]);
        }
        translate([66,0,0]) hull() {
            cube([1,4,4]);
            translate([1,0.4,0.4]) cube([1.2,3.2,3.2]);
        }
        mark("F",[34,2,4],3.2,0.45);
    }
}

module G_sht_sled() {
    difference() {
        union() {
            rrbox([34,31,2],2);
            for (x=[3,29]) translate([x,5,2]) cube([2,21,4]);
            for (y=[5,24]) translate([3,y,2]) cube([28,2,4]);
            mark("G",[17,27.5,2],4);
        }
        translate([12,10,-0.1]) cube([10,11,2.2]);
        translate([14,-0.1,-0.1]) cube([6,7,4]);
    }
}

module H_sky_top() {
    difference() {
        union() {
            rrbox([92,50,4],4);
            translate([-10,15,0]) rrbox([112,20,4],3);
            translate([27,25,4]) difference() {
                cylinder(d=30,h=18);
                translate([0,0,-0.1]) cylinder(d=16,h=18.2);
            }
            translate([66,25,4]) difference() {
                cylinder(d=28,h=31);
                translate([0,0,-0.1]) cylinder(d1=12,d2=9,h=31.2);
            }
            mark("H  SKY TOP",[46,7,4],4.5);
        }
        // Sensor apertures.
        translate([27,25,-0.1]) cylinder(d=16,h=4.2);
        translate([66,25,-0.1]) cylinder(d=10,h=4.2);
        // Friction peg sockets.
        for (x=[7,85], y=[7,43])
            translate([x,y,-0.1])
                cylinder(d=peg_d+peg_clearance_d,h=4.2);
        for (x=[-5,97])
            translate([x,25,-0.1]) hull() {
                translate([0,-4,0]) cylinder(d=4.5,h=4.2);
                translate([0,4,0]) cylinder(d=4.5,h=4.2);
            }
    }
}

module pocket_rails(c=[27,25], s=[22,18]) {
    translate([c[0]-s[0]/2-1.5,c[1]-s[1]/2-1.5,2]) {
        cube([s[0]+3+board_clearance,1.5,3]);
        translate([0,s[1]+1.5+board_clearance,0])
            cube([s[0]+3+board_clearance,1.5,3]);
        cube([1.5,s[1]+3+board_clearance,3]);
        translate([s[0]+1.5+board_clearance,0,0])
            cube([1.5,s[1]+3+board_clearance,3]);
    }
}

module I_sky_tray() {
    union() {
        rrbox([92,50,2],4);
        pocket_rails([27,25],[22,18]);
        pocket_rails([66,25],[20,18]);
        for (x=[7,85], y=[7,43])
            translate([x,y,2]) cylinder(d1=peg_d,d2=peg_d-0.1,h=4);
        mark("I  SENSOR TRAY",[46,7,2],4);
    }
}

module J_rain_raw() {
    difference() {
      union() {
        // Sloped 3 mm tray.
        hull() {
            translate([0,0,0]) cube([64,4,3]);
            translate([0,48,20]) cube([64,4,3]);
        }
        // Side lips.
        for (x=[0,61])
            hull() {
                translate([x,2,2]) cube([3,4,5]);
                translate([x,46,20]) cube([3,4,5]);
            }
        translate([0,0,2]) cube([64,4,7]);
        translate([22,47,18]) difference() {
            cube([20,8,8]);
            translate([5,-0.1,2]) cube([10,8.2,4]);
        }
        if (is_undef($show_part_labels) || $show_part_labels)
            // Side label; this becomes upward-facing after export rotation.
            translate([0,25,11]) rotate([90,0,90])
                linear_extrude(0.6)
                    text("J RAIN",size=5,font="Liberation Sans:style=Bold",
                         halign="center",valign="center");
      }
      for (x=[10,54])
          translate([x,-0.1,5.5]) rotate([-90,0,0])
              cylinder(d=4,h=4.2);
    }
}

module J_rain_mount() {
    // Rotate onto the broad left cheek: stable, support-free print orientation.
    translate([26,0,0]) rotate([0,-90,0]) J_rain_raw();
}
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

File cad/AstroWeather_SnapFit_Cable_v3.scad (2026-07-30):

/*
  SPDX-License-Identifier: AGPL-3.0-or-later
  Copyright (C) 2026 Tarun and contributors

  AstroWeather India - non-cellular snap-fit and cable-management revision 3

  Every exported STL is in its intended support-free print orientation.
  Print part 12 first and tune the parameters below before the full set.

   1 A3_SnapFit_Electronics_Box
   2 B3_Release_Lid
   3 C_Shield_Base (unchanged sensor geometry)
   4 D_Shield_Louver (print 6)
   5 E_Shield_Roof
   6 F_Shield_Rod (print 3)
   7 G_SHT31_Sled
   8 H_Sky_Head_Top
   9 I3_SnapFit_Sky_Tray
  10 J_Rain_Plate_Mount
  11 K3_Cable_Managed_Mounting_Plate
  12 L3_Fit_Kit_6_PIECES_PRINT_FIRST
  13 M3_Cable_Clip (print 6)
  14 N3_Split_Grommet (print 2)
  90 exploded assembly preview
*/

use <AstroWeather_PrintReady_v2.scad>

$fn = 64;
part_id = 90;

wall = 2.4;
lid_clearance_per_side = 0.35;
snap_tab_width = 14;
snap_tab_thickness = 1.8;
snap_tab_height = 11.2;
snap_hook = 0.75;
snap_window_clearance = 0.45;

sky_peg_shaft_d = 3.45;
sky_peg_head_d = 4.05;
sky_peg_shaft_h = 4.25;
sky_peg_head_h = 0.90;
sky_socket_d = 3.90; // Matches the enlarged H socket.
sky_top_seat_z = 7.0;
sky_peg_base_z = 6.80;
board_clearance = 0.50;

cable_entry_d = 10.0;
grommet_body_d = 9.55;
grommet_flange_d = 13.0;
grommet_cable_d = 5.4;
cable_clip_d = 5.5;

module v3_mark(txt, p=[0,0,0], size=5, h=0.55) {
    if (is_undef($show_part_labels) || $show_part_labels)
        translate(p) linear_extrude(h)
            text(txt,size=size,font="Liberation Sans:style=Bold",
                 halign="center",valign="center");
}

module snap_window(y_back=false) {
    translate([60-snap_tab_width/2-snap_window_clearance,
               y_back ? 77.3 : -0.1,
               31.3])
        cube([snap_tab_width+2*snap_window_clearance,
              2.8,
              4.6]);
}

module cable_anchor(x, y=12) {
    translate([x,y,3])
        difference() {
            union() {
                translate([-5,-4,0]) cube([10,8,6]);
                translate([-6,-5,0]) cube([12,10,1.2]);
            }
            translate([0,0,3.4])
                rotate([90,0,0]) cylinder(d=3.6,h=12,center=true);
        }
}

module board_tie_anchor(x,y) {
    translate([x,y,3])
        difference() {
            union() {
                translate([-4,-3,0]) cube([8,6,5]);
                translate([-5,-4,0]) cube([10,8,1]);
            }
            translate([0,0,3])
                rotate([90,0,0]) cylinder(d=3.4,h=9,center=true);
        }
}

module A3_box() {
    difference() {
        union() {
            difference() {
                rrbox([120,80,42],5);
                translate([wall,wall,3])
                    rrbox([120-2*wall,80-2*wall,42],3.2);
                // Two labelled down-facing entries: power and combined sensor loom.
                translate([20,-1,13])
                    rotate([-90,0,0]) cylinder(d=cable_entry_d,h=wall+2);
                translate([100,-1,13])
                    rotate([-90,0,0]) cylinder(d=cable_entry_d,h=wall+2);
                // Vent/drain slots stay on the installed underside.
                for (x=[29:21:92])
                    translate([x,18,-0.1]) rrbox([10,3,4],1);
            }
            // Generic ESP32/perfboard rails.
            for (y=[25,55]) translate([25,y,3]) cube([70,2.4,4]);
            // Low cable-routing fences guide wires away from the lid latches.
            for (x=[31,89]) translate([x,7,3]) cube([2,18,3]);
            cable_anchor(20);
            cable_anchor(100);
            for (x=[30,90], y=[33,48]) board_tie_anchor(x,y);
            v3_mark("A3  SNAP BOX",[60,68,3],5);
            v3_mark("POWER",[20,22,3],3.2);
            v3_mark("SENSORS",[100,22,3],3.2);
            if (is_undef($show_part_labels) || $show_part_labels) {
                translate([60,0,38.5]) rotate([-90,0,0])
                    linear_extrude(0.5)
                        text("PUSH",size=3.2,
                             font="Liberation Sans:style=Bold",
                             halign="center",valign="center");
                translate([60,80,38.5]) rotate([90,0,0])
                    linear_extrude(0.5)
                        text("PUSH",size=3.2,
                             font="Liberation Sans:style=Bold",
                             halign="center",valign="center");
            }
        }
        snap_window(false);
        snap_window(true);
    }
}

module snap_tongue(front=true) {
    union() {
        translate([-snap_tab_width/2,0,0])
            cube([snap_tab_width,snap_tab_thickness,snap_tab_height]);
        if (front)
            hull() {
                translate([-snap_tab_width/2,
                           -snap_hook,
                           snap_tab_height-3.2])
                    cube([snap_tab_width,snap_tab_thickness+snap_hook,0.8]);
                translate([-snap_tab_width/2,
                           0,
                           snap_tab_height-0.25])
                    cube([snap_tab_width,snap_tab_thickness,0.25]);
            }
        else
            hull() {
                translate([-snap_tab_width/2,
                           0,
                           snap_tab_height-3.2])
                    cube([snap_tab_width,snap_tab_thickness+snap_hook,0.8]);
                translate([-snap_tab_width/2,
                           0,
                           snap_tab_height-0.25])
                    cube([snap_tab_width,snap_tab_thickness,0.25]);
            }
        // Root gusset remains below the flexing section.
        hull() {
            translate([-snap_tab_width/2,0,0])
                cube([snap_tab_width,snap_tab_thickness,0.5]);
            translate([-snap_tab_width/2+2,0,2.2])
                cube([snap_tab_width-4,snap_tab_thickness,0.5]);
        }
    }
}

module B3_lid() {
    plug_x = 115.2-2*lid_clearance_per_side;
    plug_y = 75.2-2*lid_clearance_per_side;
    ox = (124-plug_x)/2;
    oy = (84-plug_y)/2;
    ring_t = 1.8;

    union() {
        rrbox([124,84,3],5.5);

        // Alignment rails. Central gaps leave each latch tongue free to flex.
        translate([ox,oy,2.8]) {
            cube([ring_t,plug_y,4.2]);
            translate([plug_x-ring_t,0,0]) cube([ring_t,plug_y,4.2]);
            for (x=[0,plug_x-34]) {
                translate([x,0,0]) cube([34,ring_t,4.2]);
                translate([x,plug_y-ring_t,0])
                    cube([34,ring_t,4.2]);
            }
        }

        // Releasable opposing latches: press both A3 windows while lifting B3.
        translate([62,oy,2.8]) snap_tongue(true);
        translate([62,oy+plug_y-snap_tab_thickness,2.8])
            snap_tongue(false);

        v3_mark("B3  RELEASE LID",[62,42,3],5.5);
        v3_mark("PRESS SIDES",[62,18,3],3.2);
    }
}

module sky_snap_peg() {
    // The split lets the two halves compress through H5, then recover above
    // its four-millimetre plate. The unsplit lower section remains robust.
    difference() {
        union() {
            cylinder(d=sky_peg_shaft_d,h=sky_peg_shaft_h);
            translate([0,0,sky_peg_shaft_h])
                cylinder(d1=sky_peg_head_d,d2=sky_peg_shaft_d,h=sky_peg_head_h);
        }
        translate([-0.3,-3,1.25]) cube([0.6,6,4.0]);
    }
}

module sky_tray_rim() {
    // A five-millimetre upward rim seats H5 above the PCB rails/fingers instead
    // of forcing its solid plate through them. The front notch passes the loom.
    difference() {
        translate([0,0,1.9]) rrbox([92,50,5.1],4);
        translate([2,2,1.8]) rrbox([88,46,5.4],2.4);
        translate([41,-0.1,2.4]) cube([10,2.3,4.8]);
    }
}

module sky_snap_mount() {
    // The pad supports H5; the pin overlaps it by 0.2 mm for one solid mesh.
    translate([0,0,2]) cylinder(d=7,h=5);
    translate([0,0,sky_peg_base_z]) sky_snap_peg();
}

module I3_sky_tray() {
    union() {
        rrbox([92,50,2],4);
        sky_tray_rim();
        pocket_rails([27,25],[22,18]);
        pocket_rails([66,25],[20,18]);
        for (x=[7,85], y=[7,43])
            translate([x,y,0]) sky_snap_mount();
        // Cable tie bridge between the two sensor pockets.
        translate([43,19,2])
            difference() {
                cube([6,12,4]);
                translate([-0.1,3,1.4]) cube([6.2,6,2.8]);
            }
        v3_mark("I3  SNAP TRAY",[46,7,2],4);
    }
}
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

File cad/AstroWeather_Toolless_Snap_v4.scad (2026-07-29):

/*
  SPDX-License-Identifier: AGPL-3.0-or-later
  Copyright (C) 2026 Tarun and contributors

  AstroWeather India - non-cellular tool-less snap assembly revision 4

  Print part 12 first. All exported parts are oriented support-free.

   1 A4 Tool-less electronics box
   2 B4 Releasable lid
   3 C4 Shield base with click sockets
   4 D4 Side-snap louver (print 6)
   5 E4 Click roof
   6 F4 Detent rod (print 3)
   7 G4 Click SHT31 sled
   8 H4 Sky head top
   9 I4 Sky tray with PCB fingers
  10 J4 Compliant rain cradle
  11 K4 Click mounting plate
  12 L4 Complete fit kit - print first
  13 M4 Cable clip (print 6)
  14 N4 Split grommet (print 2)
  15 O4 Electronics carrier
  90 Exploded assembly preview
  91 Interface preview
*/

use <AstroWeather_SnapFit_Cable_v3.scad>
use <AstroWeather_PrintReady_v2.scad>

$fn = 64;
part_id = 90;
$show_part_labels = false;

rod_nominal = 4.00;
rod_socket = 4.35;
rod_detent = 4.50;
louver_throat = 3.65;
louver_socket = 4.25;
pcb_clearance = 0.55;
pcb_hook_overlap = 0.45;
carrier_peg_shaft = 3.40;
carrier_peg_head = 3.85;
carrier_hole = 3.70;
carrier_support_z = 8.00;
carrier_base_t = 2.00;
carrier_axial_clearance = 0.10;
carrier_standoff_d = 6.50;
mount_hook_overlap = 0.40;
rain_board_width = 55.0;
rain_board_length = 40.0;

module v4_mark(txt,p=[0,0,0],size=4,h=0.50) {
    if ($show_part_labels)
        translate(p) linear_extrude(h)
            text(txt,size=size,font="Liberation Sans:style=Bold",
                 halign="center",valign="center");
}

module carrier_snap_stud() {
    union() {
        cylinder(d=carrier_peg_shaft,
                 h=carrier_base_t+carrier_axial_clearance);
        translate([0,0,carrier_base_t+carrier_axial_clearance])
            cylinder(d1=carrier_peg_head,d2=carrier_peg_shaft,h=0.9);
    }
}

module carrier_mount_post() {
    union() {
        cylinder(d=carrier_standoff_d,h=carrier_support_z-3);
        translate([0,0,carrier_support_z-3]) carrier_snap_stud();
    }
}

module A4_box() {
    union() {
        A3_box();
        // Four standoffs support O4 at Z=8 and place each retaining head
        // completely above its 2 mm base.
        for (x=[25,95],y=[20,60])
            translate([x,y,3]) carrier_mount_post();
        // External catches for K4. Press K4's four tabs outward to release.
        for (x=[35,85]) {
            translate([x,-1.1,4]) cube([10,2.2,2.2]);
            translate([x,78.9,4]) cube([10,2.2,2.2]);
        }
        v4_mark("A4 TOOLLESS",[60,59,3],4.2);
    }
}

module B4_lid() {
    B3_lid();
}

module rod_click_socket(a=0) {
    rotate([0,0,a]) translate([28,0,0])
        difference() {
            cylinder(d=10,h=8);
            translate([-rod_socket/2,-rod_socket/2,1.7])
                cube([rod_socket,rod_socket,6.5]);
            // Relief slit lets the socket expand around the rod detent.
            translate([-0.75,0,1.7]) cube([1.5,6,6.5]);
        }
}

module C4_shield_base() {
    difference() {
        union() {
            difference() {
                cylinder(d=70,h=3);
                translate([0,0,-0.1]) cylinder(d=38,h=3.2);
            }
            translate([-31,-2,0]) cube([62,4,3]);
            translate([-2,-31,0]) cube([4,62,3]);
            translate([-16,-18,3]) cube([32,2.2,5]);
            translate([-16,15.8,3]) cube([32,2.2,5]);
            for (a=[0,120,240]) rod_click_socket(a);
            // End stop and click bump for G4.
            translate([14.5,-15.7,3]) cube([2.5,31.4,4.5]);
            translate([12.7,-2,5.2]) cube([2.2,4,1.2]);
            translate([34,-10,0]) rrbox([18,20,3],3);
            v4_mark("C4 CLICK",[0,-27,3],3.8);
        }
        translate([44,0,-0.1]) hull() {
            translate([0,-4,0]) cylinder(d=4.5,h=3.2);
            translate([0,4,0]) cylinder(d=4.5,h=3.2);
        }
    }
}

module radial_snap_cut(a=0) {
    rotate([0,0,a]) {
        translate([28-louver_socket/2,-louver_socket/2,-0.1])
            cube([louver_socket,louver_socket,9.3]);
        // Narrow mouth creates two flexible retaining shoulders.
        translate([28,-louver_throat/2,-0.1])
            cube([8,louver_throat,9.3]);
    }
}

module D4_louver() {
    difference() {
        union() {
            difference() {
                cylinder(d=70,h=2.2);
                translate([0,0,-0.1]) cylinder(d=38,h=2.4);
            }
            for (a=[0,120,240])
                rotate([0,0,a]) translate([28,0,0])
                    cylinder(d=9,h=9);
            v4_mark("D4 SNAP",[0,-27,2.2],3.4);
        }
        for (a=[0,120,240]) radial_snap_cut(a);
    }
}

module E4_roof() {
    difference() {
        union() {
            cylinder(d=72,h=3);
            translate([0,0,3]) cylinder(d1=68,d2=58,h=5);
            v4_mark("E4 CLICK",[0,-25,8],3.5);
        }
        for (a=[0,120,240])
            rotate([0,0,a]) translate([28,0,-0.1]) {
                translate([-rod_socket/2,-rod_socket/2,0])
                    cube([rod_socket,rod_socket,8.3]);
                translate([-0.75,0,0]) cube([1.5,6,8.3]);
            }
    }
}

module F4_rod() {
    // Print flat. The 0.25 mm side beads click into C4/E4 relief sockets.
    union() {
        translate([2,0.25,0]) cube([64,rod_nominal,rod_nominal+0.25]);
        for (x=[1.8,65.8]) {
            translate([x,0.25,0.25]) cube([0.8,rod_nominal,rod_nominal]);
            translate([x,0,1.0]) cube([0.8,rod_detent,2.5]);
        }
        translate([0,0.65,0.65]) hull() {
            cube([1.8,3.2,3.2]);
            translate([2,0,0]) cube([0.8,3.2,3.2]);
        }
        translate([66,0.65,0.65]) hull() {
            cube([0.8,3.2,3.2]);
            translate([1.6,0.4,0.4]) cube([0.8,2.4,2.4]);
        }
        v4_mark("F4",[34,2.25,4.25],3,0.4);
    }
}

module G4_sht_sled() {
    union() {
        G_sht_sled();
        // Flexible end tongue clicks behind the C4 centre bump.
        translate([29.5,13.5,2])
            difference() {
                union() {
                    cube([4.5,4,1.6]);
                    translate([2.5,0,1.2]) cube([2,4,1.2]);
                }
                translate([-0.1,0.8,-0.1]) cube([2.8,2.4,2.2]);
            }
        v4_mark("G4",[5,15.5,1.7],2.4);
    }
}
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

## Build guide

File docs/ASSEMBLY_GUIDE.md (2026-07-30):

# Non-cellular V5.2 assembly

The supported printable set is `stl_unified_v5/`. Parts are intentionally
unmarked; identify them by filename.

1. Print and approve `L5_Fit_Kit_12_PIECES_PRINT_FIRST.stl`.
2. Secure the ESP32 and auxiliary board to O5.
3. Press O5 evenly onto the four A5 posts and confirm every retaining head is
   visible above the carrier.
4. Complete and bench-test the low-voltage wiring.
5. Latch B5 onto A5, then press A5 into the front-left K5 dock.
6. Assemble the radiation shield and click it into the circular dock.
7. Install the sky sensors in I5, route their loom through the rim notch, then
   lower H5 vertically over all four split pins. Press evenly at the four
   corners until every head appears above H5; do not twist the optical towers.
8. Install the rain board in J5 and press the sloped cradle into its four clips.
9. Route the looms below all six rear cable jaws with service and drip loops.
10. Add redundant UV-resistant safety ties before outdoor use.

See [`UNIFIED_V5.md`](UNIFIED_V5.md) for print settings, removal instructions,
validation details and physical-test limits.

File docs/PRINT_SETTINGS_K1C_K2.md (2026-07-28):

# K1C / K2 print settings

## Recommended outdoor material

Use white or light-coloured PETG for the affordable build. ASA is better for
permanent ultraviolet exposure but needs controlled ventilation and suitable
filament experience.

## PETG profile

- Nozzle: 0.4 mm.
- Layer height: 0.20 mm.
- First layer: 0.24 mm.
- Walls: 4.
- Top and bottom shell layers: 5.
- Infill: 20% gyroid; use 30% for K mounting plate.
- Nozzle: start at 240 °C and use the filament maker’s range.
- Bed: start at 75 °C.
- Supports: **off for every STL**.
- Seam: rear or aligned.
- Elephant-foot compensation: 0.15 mm if already calibrated.
- Slow external walls: 80–120 mm/s for cleaner labels.
- Keep the K1C/K2 chamber from becoming excessively hot with PETG; use the
  filament manufacturer’s guidance and watch for heat creep.

## Adhesion

- A–E, G–I, K and L: skirt only on a clean textured PEI plate.
- F rods: add a 3 mm brim or mouse ears because they are narrow.
- J rain mount: add a 5 mm brim because it prints tall on its broad side.
- Dry PETG before printing if it pops, strings, or produces rough labels.

## Import orientation

Do not use auto-orient. Every STL is already exported with its intended face at
Z=0:

- A box upright.
- B lid outer face on the bed, plug upward.
- C base flat.
- D louvre flat, spacer bosses upward; print six.
- E roof flat.
- F rod lying flat; print three.
- G sled flat.
- H sky-head top flat, optical tubes upward.
- I electronics tray flat, board guides upward.
- J rain mount standing on its broad side; this is intentional.
- K mounting plate flat.
- L fit-kit pieces flat.

## First-print decision

Print L before everything else:

- L2 should enter L1 with a light push and remain seated without force.
- L3 should press into L4 by hand without splitting L4.

If too tight, first verify flow calibration and elephant foot. Lightly sand the
test piece. For a source-level adjustment:

- increase `lid_clearance_per_side` from 0.30 to 0.40 mm;
- increase `peg_clearance_d` from 0.15 to 0.25 mm.

Re-export B, H, I and L after changing those values.

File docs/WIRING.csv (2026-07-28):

From | To | Notes
ESP32 3V3 | SHT31 VIN | Use 3.3 V
ESP32 3V3 | MLX90614 VIN | Use a module explicitly compatible with 3.3 V
ESP32 3V3 | TSL2591 VIN | Use 3.3 V
ESP32 GND | SHT31 GND | Common ground
ESP32 GND | MLX90614 GND | Common ground
ESP32 GND | TSL2591 GND | Common ground
ESP32 GPIO21 | SHT31 SDA | I2C address 0x44
ESP32 GPIO21 | MLX90614 SDA | I2C address 0x5A
ESP32 GPIO21 | TSL2591 SDA | I2C address 0x29
ESP32 GPIO22 | SHT31 SCL | I2C clock
ESP32 GPIO22 | MLX90614 SCL | I2C clock
ESP32 GPIO22 | TSL2591 SCL | I2C clock
5 V USB supply | ESP32 USB socket | 1 A phone charger or power bank is ample
ESP32 GPIO32 through 100k resistor | Rain plate electrode A | Add 470k from GPIO32 side to GND
ESP32 GPIO33 through 100k resistor | Rain plate electrode B | Add 470k from GPIO33 side to GND

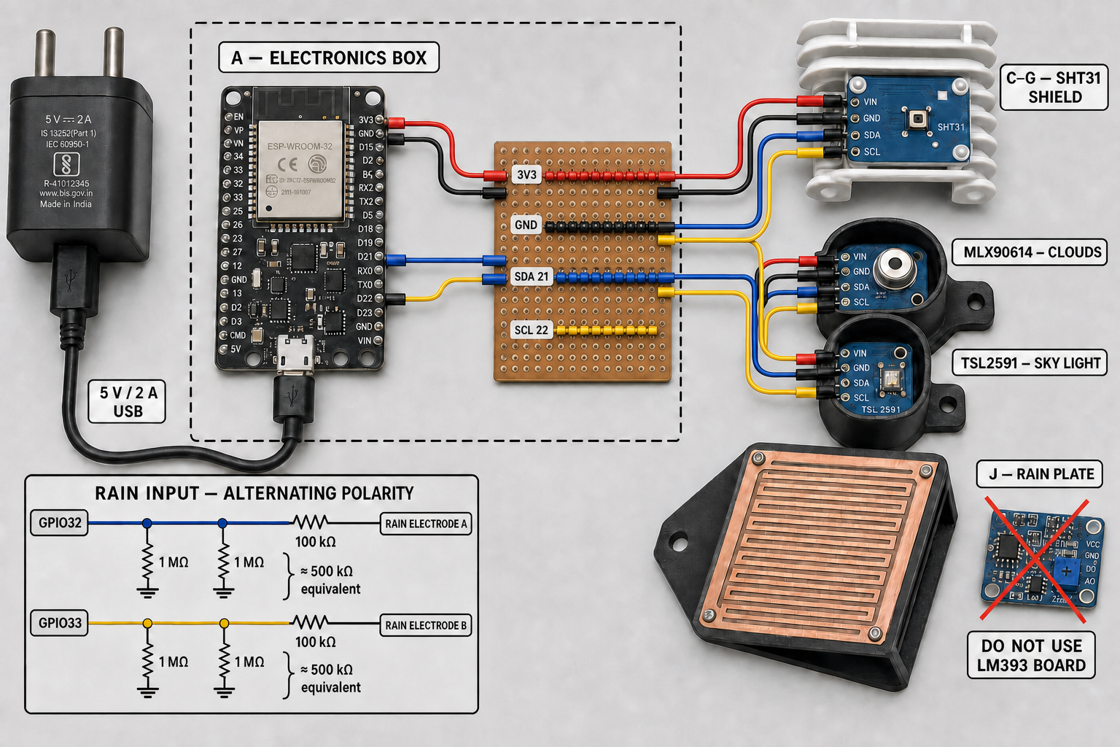
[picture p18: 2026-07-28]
assets/electronics-assembly-visual.png

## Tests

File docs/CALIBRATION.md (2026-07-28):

# Calibration

## 1. Verify temperature and humidity

Place the completed radiation shield beside a trustworthy thermometer/hygrometer
in shade for 30–60 minutes. Do not calibrate indoors and then assume the same
offset outdoors. The ESP32 box must be separated from the shield.

For a simple humidity reference, a sealed salt test can create known equilibrium
conditions, but temperature stability and correct salt preparation matter.
For astrophotography, agreement within roughly ±0.5 °C and ±3% RH is usually
more useful than aggressive software correction from a poor reference.

## 2. Learn the local cloud thresholds

The firmware uses:

```text
cloud_delta = ambient_air_temperature - infrared_sky_temperature

cloud % = 100 × (CLEAR_DELTA - cloud_delta)
                / (CLEAR_DELTA - OVERCAST_DELTA)
```

Collect readings only after dark:

1. On at least three visually clear nights, record `cloud_delta_c` every
   5–10 minutes for an hour. Use the median as `CLEAR_DELTA_C`.
2. Repeat on at least three fully overcast, dry nights. Use the median as
   `OVERCAST_DELTA_C`.
3. Enter both values near the top of the firmware and upload again.
4. Validate on mixed-cloud nights. Adjust `CLOUD_LIMIT_PERCENT` to match the
   imaging standard you actually use.

Humid Indian conditions often make clear sky look warmer in IR than dry desert
sky. This is why a universal “clear below −10 °C” rule is unreliable.

Thin high cirrus can remain cold and may be underestimated. Conversely, dew or
water on the MLX window appears warm and can look like cloud. Inspect raw
`sky_c`, `cloud_delta_c`, and recent trends whenever the result seems wrong.

## 3. Interpret thermal clarity

In this firmware:

```text
clarity_score = 100 - cloud_percent
```

It answers “how thermally clear does the zenith look after local calibration?”
It does not measure seeing, atmospheric turbulence, transparency, aerosol
optical depth, or star FWHM.

Clouds may brighten an urban sky but darken a rural sky, so a universal
light-level-to-clarity direction is impossible. The SQM estimate is reported
separately and is not used by the imaging safety advisory.

## 4. Calibrate the SQM estimate

The TSL2591 uses maximum gain and 600 ms integration. Keep those settings fixed
after calibration. The firmware calculates:

```text
visible_counts = tsl_full - tsl_ir
estimated_SQM = SQM_CAL_OFFSET - 2.5 × log10(visible_counts)
```

`SQM_CAL_OFFSET` defaults to `NAN`, so the dashboard shows `CALIBRATE` instead
of inventing a reading.

To calibrate:

1. Mount the station permanently, pointing the light-sensor opening at the
   zenith.
2. Place a reference SQM beside it with the same pointing direction.
3. Wait until astronomical darkness on a clear, Moon-free night. Avoid the
   Milky Way, direct lamps, haze, cloud and shadows across either aperture.
4. Record at least five simultaneous pairs in
   `docs/SQM_CALIBRATION_TEMPLATE.csv`. Copy `tsl_full`, `tsl_ir`, and
   `tsl_visible` from `/api/weather`.
5. Calculate the offset:

   ```bash
   python tools/calculate_sqm_offset.py docs/SQM_CALIBRATION_TEMPLATE.csv
   ```

6. Enter the recommended value near the top of the firmware:

   ```cpp
   float SQM_CAL_OFFSET = 27.1234;
   ```

7. Upload the firmware and repeat simultaneous readings on at least two
   additional nights.

For a single paired observation, the equivalent calculation is:

```text
SQM_CAL_OFFSET = reference_SQM + 2.5 × log10(visible_counts)
```

The API reports `tsl_light_valid=false` and suppresses the SQM estimate when the
sensor has no usable visible counts or either raw channel is near saturation.
Changing the sensor, optical tube, window, paint, mounting angle, gain or
integration time invalidates the offset.

The displayed Bortle class is a heuristic conversion from estimated SQM:

| Estimated SQM (mag/arcsec²) | Display |
|---:|---:|
| 21.99 or higher | Bortle 1 |
| 21.89–21.98 | Bortle 2 |
| 21.69–21.88 | Bortle 3 |
| 20.49–21.68 | Bortle 4 |
| 19.50–20.48 | Bortle 5 |
| 18.94–19.49 | Bortle 6 |
| 18.38–18.93 | Bortle 7 |
| 17.80–18.37 | Bortle 8 |
| Below 17.80 | Bortle 9 |

Bortle is fundamentally a visual assessment of the whole sky. Treat this value
as a convenient label, not a measured Bortle classification. Moonlight, the
Milky Way, airglow, haze, cloud and nearby lights can shift it substantially.

## 5. Dew and imaging advisory

Default advisory limits are:

- RH below 90%;
- air temperature more than 2 °C above dew point;
- estimated cloud below 55%.

These are conservative starting points, not safety standards. A dew heater on
the telescope may allow imaging closer to dew point, but it does not stop
condensation on the station optics.

## 6. Keep a validation log

For the first month, note timestamp, Moon, visual cloud, haze, actual imaging
quality, and the JSON reading. Re-tune thresholds for monsoon, winter, and very
dry seasons if their baselines differ.

## 7. Calibrate the rain plate

1. Let the clean plate dry completely and record `rain_raw` for ten readings.
2. Mist it with a few separate tap-water droplets and record ten readings.
3. Set `RAIN_THRESHOLD_RAW` midway between the highest dry value and the lowest
   repeatable droplet value.
4. Test with a fine spray from several directions. Confirm that
   `rain_detected` becomes true and `advisory_safe` becomes false.
5. The firmware holds rain unsafe for ten minutes after a wet reading. Change
   `600000UL` only after real testing.

Dew, insects, dirt, sea salt, and condensation can trigger the plate. That is a
safe failure direction for attended imaging but makes it unsuitable as the sole
sensor for an unattended roof. The exposed traces are consumable even with
polarity reversal; inspect them monthly during monsoon conditions.

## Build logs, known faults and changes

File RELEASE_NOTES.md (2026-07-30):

# Non-Cellular V5.2

This repository exposes one current non-cellular edition.

## Current release

- one clean 210 × 200 mm unified backplane;
- tool-less removable enclosure, radiation shield, sky head and rain cradle;
- corrected electronics-carrier supports and retaining heads;
- collision-free enclosure, shield, sky and rain docks;
- connected 6 mm rain pedestals matching the sloped cradle;
- relocated mounting slot clear of the rain support;
- flexible 4.6 mm cable-retaining jaws;
- twelve-piece fit kit;
- corrected H5/I5 sky-head interface with a raised protective rim, support
  pads, compliant split pins and matched sockets;
- editable OpenSCAD and validated STL files;
- Wi-Fi dashboard, Telegram, JSON, ASCOM Alpaca and INDI support.

Users with original V5 files from commit `88b9ef8` must replace A5 and K5.
Everyone with V5.1 or earlier must replace H5, I5 and L5 before assembling the
sky head.

Physical fit, sealing, calibration and unattended safety remain field tests.
The project is licensed under GNU AGPL-3.0-or-later.

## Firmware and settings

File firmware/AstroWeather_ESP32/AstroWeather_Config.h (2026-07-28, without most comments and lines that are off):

#pragma once
#include <Preferences.h>
#define DEFAULT_ADMIN_PASSWORD "astroadmin"
#define DEFAULT_SETUP_AP_PASSWORD "astroclear"
struct AstroSettings {
  String hostname = "astroweather";
  String wifiSsid;
  String wifiPassword;
  String setupApPassword = DEFAULT_SETUP_AP_PASSWORD;
  String adminPassword = DEFAULT_ADMIN_PASSWORD;
  bool telegramEnabled = false;
  String telegramToken;
  String telegramChatId;
  uint16_t reportMinutes = 60;
  bool notifyUnsafe = true;
  bool notifyRecovery = true;
  bool notifyRain = true;
  bool notifyStartup = true;
  int utcOffsetMinutes = 330; // India Standard Time by default.
  uint16_t rainLatchMinutes = 10;
};
AstroSettings settings;
unsigned long settingsRestartAt = 0;
String settingsCsrfToken;
bool telegramSendTest();
bool isPlaceholderCredential(const String &value) {
  return value.length() == 0 || value.startsWith("YOUR_");
}
String htmlEscape(const String &input) {
  String output;
  output.reserve(input.length() + 16);
  for (size_t i = 0; i < input.length(); ++i) {
    switch (input[i]) {
      case '&': output += F("&amp;"); break;
      case '<': output += F("&lt;"); break;
      case '>': output += F("&gt;"); break;
      case '"': output += F("&quot;"); break;
      case '\'': output += F("&#39;"); break;
      default: output += input[i];
    }
  }
  return output;
}
bool validHostname(const String &hostname) {
  if (hostname.length() < 1 || hostname.length() > 32 ||
      hostname[0] == '-' || hostname[hostname.length() - 1] == '-') return false;
  for (size_t i = 0; i < hostname.length(); ++i) {
    char c = hostname[i];
    if (!isalnum((unsigned char)c) && c != '-') return false;
  }
  return true;
}
bool settingsAuthenticated() {
  if (server.authenticate("admin", settings.adminPassword.c_str())) return true;
  server.requestAuthentication(BASIC_AUTH, "AstroWeather settings");
  return false;
}
bool settingsCsrfValid() {
  return server.hasArg("csrf") && server.arg("csrf") == settingsCsrfToken;
}
void applySettingsToRuntime() {
  HUMIDITY_LIMIT = clampf(HUMIDITY_LIMIT, 1.0f, 100.0f);
  DEW_MARGIN_LIMIT_C = clampf(DEW_MARGIN_LIMIT_C, 0.0f, 20.0f);
  CLOUD_LIMIT_PERCENT = clampf(CLOUD_LIMIT_PERCENT, 0.0f, 100.0f);
  RAIN_THRESHOLD_RAW = constrain(RAIN_THRESHOLD_RAW, 0, 4095);
  settings.rainLatchMinutes =
      constrain((int)settings.rainLatchMinutes, 1, 120);
}
void loadSettings() {
  char csrf[17];
  snprintf(csrf, sizeof(csrf), "%08lx%08lx",
           (unsigned long)esp_random(), (unsigned long)esp_random());
  settingsCsrfToken = csrf;
  Preferences prefs;
  prefs.begin("astroweather", true);
  settings.hostname = prefs.getString("host", "astroweather");
  settings.wifiSsid = prefs.getString("wifi_ssid", "");
  settings.wifiPassword = prefs.getString("wifi_pass", "");
  settings.setupApPassword =
      prefs.getString("ap_pass", DEFAULT_SETUP_AP_PASSWORD);
  settings.adminPassword =
      prefs.getString("admin_pass", DEFAULT_ADMIN_PASSWORD);
  settings.telegramEnabled = prefs.getBool("tg_enable", false);
  settings.telegramToken = prefs.getString("tg_token", "");
  settings.telegramChatId = prefs.getString("tg_chat", "");
  settings.reportMinutes = prefs.getUShort("tg_mins", 60);
  settings.notifyUnsafe = prefs.getBool("tg_unsafe", true);
  settings.notifyRecovery = prefs.getBool("tg_safe", true);
  settings.notifyRain = prefs.getBool("tg_rain", true);
  settings.notifyStartup = prefs.getBool("tg_start", true);
  settings.utcOffsetMinutes = prefs.getInt("utc_offset", 330);
  CLEAR_DELTA_C = prefs.getFloat("clear_delta", CLEAR_DELTA_C);
  OVERCAST_DELTA_C = prefs.getFloat("cloud_delta", OVERCAST_DELTA_C);
  HUMIDITY_LIMIT = prefs.getFloat("humid_limit", HUMIDITY_LIMIT);
  DEW_MARGIN_LIMIT_C = prefs.getFloat("dew_limit", DEW_MARGIN_LIMIT_C);
  CLOUD_LIMIT_PERCENT = prefs.getFloat("cloud_limit", CLOUD_LIMIT_PERCENT);
  RAIN_THRESHOLD_RAW = prefs.getInt("rain_raw", RAIN_THRESHOLD_RAW);
  settings.rainLatchMinutes = prefs.getUShort("rain_latch", 10);
  SQM_CAL_OFFSET = prefs.getFloat("sqm_offset", SQM_CAL_OFFSET);
  prefs.end();
  if (settings.wifiSsid.length() == 0 &&
      !isPlaceholderCredential(String(WIFI_SSID))) {
    settings.wifiSsid = WIFI_SSID;
    settings.wifiPassword = WIFI_PASSWORD;
  }
  if (!validHostname(settings.hostname)) settings.hostname = "astroweather";
  if (settings.setupApPassword.length() < 8)
    settings.setupApPassword = DEFAULT_SETUP_AP_PASSWORD;
  if (settings.adminPassword.length() < 8)
    settings.adminPassword = DEFAULT_ADMIN_PASSWORD;
  if (settings.reportMinutes != 0 && settings.reportMinutes != 30 &&
      settings.reportMinutes != 60) settings.reportMinutes = 60;
  settings.utcOffsetMinutes = constrain(settings.utcOffsetMinutes, -720, 840);
  applySettingsToRuntime();
}
void saveSettingsToNvs() {
  Preferences prefs;
  prefs.begin("astroweather", false);
  prefs.putString("host", settings.hostname);
  prefs.putString("wifi_ssid", settings.wifiSsid);
  prefs.putString("wifi_pass", settings.wifiPassword);
  prefs.putString("ap_pass", settings.setupApPassword);
  prefs.putString("admin_pass", settings.adminPassword);
  prefs.putBool("tg_enable", settings.telegramEnabled);
  prefs.putString("tg_token", settings.telegramToken);
  prefs.putString("tg_chat", settings.telegramChatId);
  prefs.putUShort("tg_mins", settings.reportMinutes);
  prefs.putBool("tg_unsafe", settings.notifyUnsafe);
  prefs.putBool("tg_safe", settings.notifyRecovery);
  prefs.putBool("tg_rain", settings.notifyRain);
  prefs.putBool("tg_start", settings.notifyStartup);
  prefs.putInt("utc_offset", settings.utcOffsetMinutes);
  prefs.putFloat("clear_delta", CLEAR_DELTA_C);
  prefs.putFloat("cloud_delta", OVERCAST_DELTA_C);
  prefs.putFloat("humid_limit", HUMIDITY_LIMIT);
  prefs.putFloat("dew_limit", DEW_MARGIN_LIMIT_C);
  prefs.putFloat("cloud_limit", CLOUD_LIMIT_PERCENT);
  prefs.putInt("rain_raw", RAIN_THRESHOLD_RAW);
  prefs.putUShort("rain_latch", settings.rainLatchMinutes);
  prefs.putFloat("sqm_offset", SQM_CAL_OFFSET);
  prefs.end();
}
String checked(bool value) {
  return value ? " checked" : "";
}
String selected(int actual, int option) {
  return actual == option ? " selected" : "";
}
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

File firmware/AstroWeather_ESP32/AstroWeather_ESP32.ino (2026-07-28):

/*
  AstroWeather India v1.3
  ESP32 + SHT31 + MLX90614 + TSL2591

  SPDX-License-Identifier: AGPL-3.0-or-later
  Copyright (C) 2026 Tarun and contributors

  Advisory weather data only. Its low-cost rain plate is consumable and it
  must never be the sole input to an unattended roof-closing system.
*/

#include <WiFi.h>
#include <WebServer.h>
#include <ESPmDNS.h>
#include <Wire.h>
#include <Adafruit_SHT31.h>
#include <Adafruit_MLX90614.h>
#include <Adafruit_TSL2591.h>
#include "secrets.h"

WebServer server(80);
Adafruit_SHT31 sht31 = Adafruit_SHT31();
Adafruit_MLX90614 mlx = Adafruit_MLX90614();
Adafruit_TSL2591 tsl = Adafruit_TSL2591(2591);

// Tune these after at least 3 clear and 3 overcast local nights.
float CLEAR_DELTA_C = 18.0;      // ambient - sky under locally clear conditions
float OVERCAST_DELTA_C = 7.0;    // ambient - sky under locally overcast conditions
float HUMIDITY_LIMIT = 90.0;
float DEW_MARGIN_LIMIT_C = 2.0;
float CLOUD_LIMIT_PERCENT = 55.0;
int RAIN_THRESHOLD_RAW = 700;    // Calibrate between dry and droplet readings.

// Leave as NAN until calibrated against a reference SQM. With the TSL2591 fixed
// at maximum gain and 600 ms integration:
// offset = reference_SQM + 2.5 * log10(reference_visible_counts)
float SQM_CAL_OFFSET = NAN;
const uint16_t TSL_SATURATION_COUNTS = 65000;

// Cheapest rain input: bare exposed-trace plate, no LM393 board.
// Each GPIO connects to one plate electrode through 100k; each GPIO also has
// 470k to GND. Alternating polarity and a very low duty cycle reduce corrosion.
const int RAIN_A_PIN = 32;
const int RAIN_B_PIN = 33;

bool shtOK = false, mlxOK = false, tslOK = false;
float airC = NAN, humidity = NAN, dewC = NAN, skyC = NAN;
float cloudDeltaC = NAN, cloudPercent = NAN, clarityScore = NAN;
float lux = NAN, sqmEstimate = NAN;
uint16_t tslFull = 0, tslIR = 0, tslVisible = 0;
int bortleEstimate = 0;
bool tslLightValid = false;
unsigned long lastRead = 0;
unsigned long lastRainRead = 0, rainLatchUntil = 0;
int rainRaw = 0;
bool rainDetected = false;

const char INDEX_HTML[] PROGMEM = R"rawliteral(
<!doctype html><html><head><meta name="viewport" content="width=device-width,initial-scale=1">
<title>AstroWeather</title><style>
body{font-family:system-ui;background:#07111d;color:#e9f2ff;margin:0;padding:18px}
.wrap{max-width:850px;margin:auto}.top{display:flex;justify-content:space-between;align-items:center}
.grid{display:grid;grid-template-columns:repeat(auto-fit,minmax(160px,1fr));gap:12px}
.card{background:#102238;border:1px solid #244462;border-radius:14px;padding:15px}
.v{font-size:1.7rem;font-weight:700;margin-top:5px}.ok{color:#63e69b}.bad{color:#ff8178}
.note{color:#9bb0c8;font-size:.9rem;line-height:1.4}h1{font-size:1.5rem}
a{color:#79b8ff}.settings{background:#18324e;border-radius:8px;padding:7px 10px;text-decoration:none}
</style></head><body><div class="wrap">
<div class="top"><h1>AstroWeather India</h1><div><span id="safe">Reading…</span> &nbsp; <a class=settings href="/settings">Settings</a></div></div>
<div class="grid" id="grid"></div>
<p class="note">Advisory only: “Clarity” is the calibrated IR cloud score. SQM and Bortle are estimates from the
TSL2591 and remain unavailable until reference calibration. Never use this alone to control an unattended roof.</p>
</div><script>
const f=(x,n=1)=>x===null?'—':Number(x).toFixed(n);
async function tick(){let d=await (await fetch('/api/weather')).json();
let sqm=d.sqm_estimate===null?(d.sqm_calibrated?'OUT OF RANGE':'CALIBRATE'):f(d.sqm_estimate,2)+' mag/arcsec²';
let bortle=d.bortle_estimate===null?'—':'Bortle '+d.bortle_estimate;
let a=[['Air',f(d.air_c)+' °C'],['Humidity',f(d.humidity)+' %'],
['Dew point',f(d.dew_c)+' °C'],['Dew margin',f(d.dew_margin_c)+' °C'],
['Sky IR',f(d.sky_c)+' °C'],['Cloud delta',f(d.cloud_delta_c)+' °C'],
['Cloud estimate',f(d.cloud_percent,0)+' %'],['Clarity',f(d.clarity_score,0)+' / 100'],
['SQM estimate',sqm],['Estimated Bortle',bortle],
['Zenith light',f(d.lux,6)+' lux'],['Rain plate',d.rain_detected?'WET':'dry'],
['Wi-Fi',d.wifi_connected?(d.wifi_rssi_dbm+' dBm'):'setup AP'],
['Telegram',d.telegram_enabled?(d.telegram_report_minutes?d.telegram_report_minutes+' min':'alerts only'):'off']];
document.querySelector('#grid').innerHTML=a.map(x=>`<div class=card>${x[0]}<div class=v>${x[1]}</div></div>`).join('');
let s=document.querySelector('#safe');s.textContent=d.advisory_safe?'ADVISORY: OK':'ADVISORY: UNSAFE';
s.className=d.advisory_safe?'ok':'bad'}tick();setInterval(tick,10000);
</script></body></html>)rawliteral";

float dewPoint(float t, float rh) {
  if (!isfinite(t) || !isfinite(rh) || rh <= 0) return NAN;
  const float a = 17.62, b = 243.12;
  float g = log(rh / 100.0) + (a * t) / (b + t);
  return (b * g) / (a - g);
}

float clampf(float v, float lo, float hi) {
  return v < lo ? lo : (v > hi ? hi : v);
}

#include "AstroWeather_Config.h"

int sqmToEstimatedBortle(float sqm) {
  // A convenient heuristic, not a measurement of John Bortle's visual scale.
  if (!isfinite(sqm)) return 0;
  if (sqm >= 21.99) return 1;
  if (sqm >= 21.89) return 2;
  if (sqm >= 21.69) return 3;
  if (sqm >= 20.49) return 4;
  if (sqm >= 19.50) return 5;
  if (sqm >= 18.94) return 6;
  if (sqm >= 18.38) return 7;
  if (sqm >= 17.80) return 8;
  return 9;
}

int rainOneWay(int drivePin, int sensePin) {
  pinMode(drivePin, OUTPUT);
  digitalWrite(drivePin, HIGH);
  pinMode(sensePin, INPUT);
  delay(4);
  int v = analogRead(sensePin);
  digitalWrite(drivePin, LOW);
  pinMode(drivePin, INPUT);
  pinMode(sensePin, INPUT);
  delay(2);
  return v;
}

void readRain() {
  // Swap polarity so deposited metal is not continuously driven one way.
  int ab = rainOneWay(RAIN_A_PIN, RAIN_B_PIN);
  int ba = rainOneWay(RAIN_B_PIN, RAIN_A_PIN);
  rainRaw = (ab + ba) / 2;
  bool wetNow = rainRaw >= RAIN_THRESHOLD_RAW;
  if (wetNow)
    rainLatchUntil = millis() +
      (unsigned long)settings.rainLatchMinutes * 60000UL;
  rainDetected = wetNow || ((long)(rainLatchUntil - millis()) > 0);
}

void readSensors() {
  if (shtOK) {
    float t = sht31.readTemperature();
    float h = sht31.readHumidity();
    if (isfinite(t)) airC = t;
    if (isfinite(h)) humidity = h;
  }
  if (mlxOK) {
    float s = mlx.readObjectTempC();
    if (isfinite(s)) skyC = s;
  }
  if (tslOK) {
    uint32_t lum = tsl.getFullLuminosity();
    tslIR = lum >> 16;
    tslFull = lum & 0xFFFF;
    tslVisible = tslFull > tslIR ? tslFull - tslIR : 0;
    tslLightValid = tslVisible > 0 &&
                    tslFull < TSL_SATURATION_COUNTS &&
                    tslIR < TSL_SATURATION_COUNTS;
    if (tslLightValid) {
      float measuredLux = tsl.calculateLux(tslFull, tslIR);
      lux = isfinite(measuredLux) && measuredLux >= 0 ? measuredLux : NAN;
      sqmEstimate = isfinite(SQM_CAL_OFFSET)
        ? SQM_CAL_OFFSET - 2.5 * log10((float)tslVisible)
        : NAN;
      bortleEstimate = sqmToEstimatedBortle(sqmEstimate);
    } else {
      lux = NAN;
      sqmEstimate = NAN;
      bortleEstimate = 0;
    }
  }

  dewC = dewPoint(airC, humidity);
  cloudDeltaC = airC - skyC;
  if (isfinite(cloudDeltaC) && CLEAR_DELTA_C > OVERCAST_DELTA_C) {
    cloudPercent = 100.0 * (CLEAR_DELTA_C - cloudDeltaC) /
                   (CLEAR_DELTA_C - OVERCAST_DELTA_C);
    cloudPercent = clampf(cloudPercent, 0, 100);
    clarityScore = 100.0 - cloudPercent;
  }
}

bool advisorySafe() {
  if (!shtOK || !mlxOK || !isfinite(humidity) || !isfinite(dewC) ||
      !isfinite(cloudPercent)) return false;
  return humidity < HUMIDITY_LIMIT &&
         (airC - dewC) > DEW_MARGIN_LIMIT_C &&
         cloudPercent < CLOUD_LIMIT_PERCENT &&
         !rainDetected;
}

String numOrNull(float v, int digits=2) {
  return isfinite(v) ? String(v, digits) : "null";
}

#include "AstroWeather_Telegram.h"

void apiWeather() {
  String j = "{";
  j += "\"air_c\":" + numOrNull(airC) + ",";
  j += "\"humidity\":" + numOrNull(humidity) + ",";
  j += "\"dew_c\":" + numOrNull(dewC) + ",";
  j += "\"dew_margin_c\":" + numOrNull(airC-dewC) + ",";
  j += "\"sky_c\":" + numOrNull(skyC) + ",";
  j += "\"cloud_delta_c\":" + numOrNull(cloudDeltaC) + ",";
  j += "\"cloud_percent\":" + numOrNull(cloudPercent) + ",";
  j += "\"clarity_score\":" + numOrNull(clarityScore) + ",";
  j += "\"lux\":" + numOrNull(lux,6) + ",";
  j += "\"tsl_full\":" + String(tslFull) + ",";
  j += "\"tsl_ir\":" + String(tslIR) + ",";
  j += "\"tsl_visible\":" + String(tslVisible) + ",";
  j += "\"tsl_light_valid\":" + String(tslLightValid ? "true":"false") + ",";
  j += "\"sqm_estimate\":" + numOrNull(sqmEstimate) + ",";
  j += "\"sqm_calibrated\":" + String(isfinite(SQM_CAL_OFFSET) ? "true":"false") + ",";
  j += "\"bortle_estimate\":";
  j += bortleEstimate > 0 ? String(bortleEstimate) : "null";
  j += ",";
  j += "\"rain_raw\":" + String(rainRaw) + ",";
  j += "\"sht_ok\":" + String(shtOK ? "true":"false") + ",";
  j += "\"mlx_ok\":" + String(mlxOK ? "true":"false") + ",";
  j += "\"tsl_ok\":" + String(tslOK ? "true":"false") + ",";
  j += "\"advisory_safe\":" + String(advisorySafe() ? "true":"false") + ",";
  j += "\"rain_detected\":" + String(rainDetected ? "true":"false") + ",";
  j += "\"wifi_connected\":" +
       String(WiFi.status() == WL_CONNECTED ? "true":"false") + ",";
  j += "\"wifi_rssi_dbm\":";
  j += WiFi.status() == WL_CONNECTED ? String(WiFi.RSSI()) : "null";
  j += ",";
  j += "\"telegram_enabled\":" +
       String(settings.telegramEnabled ? "true":"false") + ",";
  j += "\"telegram_report_minutes\":" + String(settings.reportMinutes) + ",";
  j += "\"firmware_version\":\"1.3.0\",";
  j += "\"uptime_s\":" + String(millis()/1000);
  j += "}";
  server.send(200, "application/json", j);
}

#include "AstroWeather_Alpaca.h"

void setup() {
  Serial.begin(115200);
  loadSettings();
  Wire.begin(21, 22);
  analogReadResolution(12);
  pinMode(RAIN_A_PIN, INPUT);
  pinMode(RAIN_B_PIN, INPUT);
  shtOK = sht31.begin(0x44);
  mlxOK = mlx.begin();
  tslOK = tsl.begin();
  if (tslOK) {
    tsl.setGain(TSL2591_GAIN_MAX);
    tsl.setTiming(TSL2591_INTEGRATIONTIME_600MS);
  }
  setupWiFi();
  MDNS.begin(settings.hostname.c_str());
  server.on("/", [](){ server.send_P(200, "text/html", INDEX_HTML); });
  server.on("/api/weather", apiWeather);
  server.on("/health", [](){ server.send(200, "text/plain", "ok"); });
  registerSettingsRoutes();
  alpacaBegin();
  server.begin();
  readSensors();
  readRain();
  lastRead = millis();
  telegramBegin();
  Serial.print("Open http://");
  Serial.println(WiFi.status() == WL_CONNECTED
      ? WiFi.localIP() : WiFi.softAPIP());
}

void loop() {
  server.handleClient();
  alpacaLoop();
  settingsLoop();
  if (millis() - lastRead >= 10000) {
    lastRead = millis();
    readSensors();
  }
  if (millis() - lastRainRead >= 2000) {
    lastRainRead = millis();
    readRain();
  }
  telegramLoop();
  delay(2);
}

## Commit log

2026-07-28 Publish sanitized AstroWeather India v1.0
    [A_Electronics_Box.stl, AstroWeather_PrintReady_v2.scad, BOM_India.csv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]
2026-07-28 Add calibrated SQM and Bortle estimates (#1)
    [PARTS_CHECKLIST.csv, SQM_CALIBRATION_TEMPLATE.csv]
2026-07-28 Add ASCOM Alpaca and INDI compatibility (#2)
    * Add ASCOM Alpaca and INDI compatibility
    * Support packaged INDI development libraries
    * Use packaged JSON library for INDI driver
    ---------
2026-07-29 Add non-cellular snap-fit cable-management v3
    [A3_SnapFit_Electronics_Box.stl, AstroWeather_SnapFit_Cable_v3.scad, B3_Release_Lid.stl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]
2026-07-29 Add fully tool-less snap assembly v4
    [A4_Toolless_Electronics_Box.stl, AstroWeather_Toolless_Snap_v4.scad, B4_Release_Lid.stl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]
2026-07-29 Remove physical labels from tool-less v4 parts
    [A4_Toolless_Electronics_Box.stl, AstroWeather_PrintReady_v2.scad, AstroWeather_SnapFit_Cable_v3.scad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]
2026-07-29 Add unified single-base mechanical v5
    [A5_Clean_Electronics_Box.stl, AstroWeather_Unified_Base_v5.scad, B5_Release_Lid.stl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]
2026-07-29 Fix V5 carrier and unified dock clearances
    [A4_Toolless_Electronics_Box.stl, A5_Clean_Electronics_Box.stl, AstroWeather_Toolless_Snap_v4.scad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]
2026-07-29 docs: present only non-cellular V5.1
    [A3_SnapFit_Electronics_Box.stl, A4_Toolless_Electronics_Box.stl, A_Electronics_Box.stl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]
2026-07-30 Fix H5 and I5 sky-head fit for V5.2
    [AstroWeather_PrintReady_v2.scad, AstroWeather_SnapFit_Cable_v3.scad, AstroWeather_Unified_Base_v5.scad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]

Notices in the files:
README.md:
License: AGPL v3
